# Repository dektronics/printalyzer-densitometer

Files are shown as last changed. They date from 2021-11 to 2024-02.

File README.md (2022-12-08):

# Printalyzer Densitometer

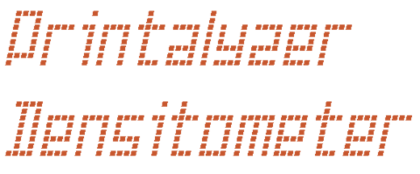
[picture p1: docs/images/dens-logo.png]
Printalyzer Densitometer Logo


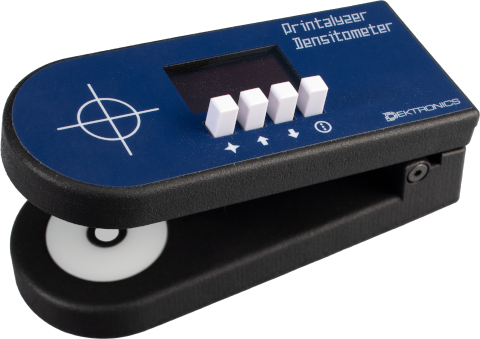
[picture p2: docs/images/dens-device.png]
Printalyzer Densitometer Device


## Introduction

The Printalyzer Densitometer is a project whose goal is the creation of an
affordable reflection and transmission densitometer for photographic darkroom
use.

It was initially conceived as an accessory to complement the
[Printalyzer Enlarging Timer & Exposure Meter](https://github.com/dektronics/printalyzer-timer)
to ease the process of creating paper profiles. However, given the general
utility of such a device, it has been spun off as a separate project in its
own right.

A good overview of the project can be found in these blog posts:
* [The Printalyzer Densitometer Project](https://hecgeek.blogspot.com/2021/07/the-printalyzer-densitometer-project.html)

This project, using hardware tagged as "Revision C" and labeled as DPD-100, is currently shipping as an official Dektronics [product](https://www.dektronics.com/printalyzer-densitometer). Links to the user manual and regulatory compliance documents can be found on the product website.

## Project Layout

### Hardware
The "hardware" directory contains [KiCad](https://www.kicad.org/) projects
with the complete circuit schematics, bill-of-materials, and
PCB layouts.

### Software
The "software" directory contains all the source code for the firmware
that runs on the hardware.

### Enclosure
The "enclosure" directory contains any CAD models and related resources
necessary to physically assemble the device.

## License
Individual directories will contain LICENSE files as needed, with relevant
details. Generally, the hardware will be CC BY-SA and the software will be
BSD 3-Clause. However, external resources may have their own individual license terms.

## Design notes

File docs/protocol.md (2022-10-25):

USB Control Protocol
====================

The Printalyzer Densitometer presents itself to a host computer as a USB CDC
device, which is essentially a virtual serial port. Through this interface,
it is possible to configure and control all aspects of the device.
This document covers that protocol.

## Data Formats

All command and response lines are terminated by a CRLF (`\r\n`).

### Command Format

Each command is sent in a standardized form:

`<TYPE><CATEGORY> <ACTION>[,<ARGS>]`
* **TYPE** values:
  * `S` - Set (change a value or state)
  * `G` - Get (return a value or state)
  * `I` - Invoke (perform some action on the system)
* **CATEGORY** values:
  * `S` - System (top-level system commands)
  * `M` - Measurement (commands related to density measurements)
  * `C` - Calibration (commands related to device calibration)
  * `D` - Diagnostics (general diagnostic commands)
* **ACTION** values are specific to each category, and documented in the following sections
* **ARGS** values are specific to each action, and not all actions may have them

### Response Format

Command responses typically fit a format that is a mirror of the command that
triggered them, except the `[,<ARGS>]` field is changed to represent
information specific to that particular command response.

The common formats for these response arguments are:
* `OK` - The command completed successfully, with no further information
* `ERR` - The command failed
* `NAK` - The command was either unrecognized or can't be processed in the current system state
* `A,B,C,D` - A comma-separated list of elements
  * Strings in this list may be quoted
  * Floating point values are returned in a little-endian hex encoded format
* A multi-line response as follows:
  ```
  TC ACTION,[[\r\n
  Line 1
  Line 2
  ...
  ]]\r\n  
  ```

### Density Format

Density readings are sent out-of-band whenever a reading is taken on the device,
and are not sent in response to commands. They follow the format of:

`<R/T><+/->#.##D`

An example of a density reading would be something like `R+0.20D` or `T+2.85D`.

### Logging Format

Redirected log messages have a unique prefix of `L/`, where "L" is the logging level.
By looking for this pattern, they can be filtered out from the rest of the command
protocol. By default, log messages are not redirected out the USB CDC interface.

Expected log levels include: `A`, `E`, `W`, `I`, `D`, and `V`

## Commands

Note: Commands that could conflict with the local device user interface
may require that the device first be placed into "remote control" mode.
If sent outside of this mode, they may fail with a **NAK**. Commands of
this type are marked below.

Commands that lack a documented response format will return either `OK` or `ERR`.

### System Commands

* `GS V` - Get project name and version
  * Response: `GS V,<Project name>,<Version>`
* `GS B` - Get firmware build information
  * Response: `GS B,<Build date>,<Build describe>,<Checksum>`
* `GS DEV`  - Get device information
  * Response: `GS DEV,<HAL Version>,<MCU Device ID>,<MCU Revision ID>,<SysClock Frequency>`
* `GS RTOS` - Get FreeRTOS information
  * Response: `GS RTOS,<FreeRTOS Version>,<Heap Free>,<Heap Watermark>,<Task Count>`
* `GS UID`  - Get device unique ID
  * Response: `GS UID,<UID>`
* `GS ISEN` - Internal sensor readings
  * Response: `GS ISEN,<VDDA>,<Temperature>`
  * Note: Response elements have unit suffixes appended, so it looks like "3300mV,24.5C"
* `IS REMOTE,n` - Invoke remote control mode (enable = 1, disable = 0)
  * Response: `IS REMOTE,n`
* `SS DISP,text` - Write the provided text to the display
  * Note: Line breaks are sent as the literal text "\n"
    and backslashes are sent as the literal text "\\"

### Measurement Commands

* `GM REFL` - Get last reflection measurement
  * Response: `GM REFL,<D>`
* `GM TRAN` - Get last transmission measurement
  * Response: `GM TRAN,<D>`
* `SM FORMAT,x` - Change measurement output format
  * Possible measurement formats are:
    * `BASIC` - The default format, which just includes the measurement mode
      and density value in a human-readable form, to 2 decimal places
    * `EXT` - Appends the density, zero offset, raw basic count,
      and slope corrected basic count sensor readings in the hex encoded format
  * Note: The active format will revert to **BASIC** upon disconnect
* `SM UNCAL,x` - Allow measurements without target calibration (0=false, 1=true)
  * Note: This setting will revert to false upon disconnect

### Calibration Commands

* `IC GAIN` - Invoke the sensor gain calibration process ***(remote mode)***
  * This is a long process in which the device must be held closed.
    It will automatically abort if the hinge detect switch is released
    during the process.
  * The result of this process will be updated measurement light and
    sensor gain calibration values.
  * While running, there will be a series of `STATUS` responses followed by
    a single `OK` or `ERR` response.
  * Status is reported via the following responses:
    * `IC GAIN,STATUS,n,m` where n is an enumerated value as follows:
      * 0 = initializing
      * 1 = measuring medium gain (m = 0 or 1)
      * 2 = measuring high gain (m = 0 or 1)
      * 3 = measuring maximum gain (m = 0 or 1)
      * 4 = calibration process failed
      * 5 = finding gain measurement brightness (m = progress)
      * 6 = waiting between measurements (m = index)
      * 7 = calibration process complete
    * `IC GAIN,OK` - Gain calibration process is complete
    * `IC GAIN,ERR` - Gain calibration process has failed
* `GC LIGHT` - Get measurement light calibration values
  * Response: `GC LIGHT,<REFL>,<TRAN>`
* `SC LIGHT,<REFL>,<TRAN>` - Set measurement light calibration values
  * The values set the duty cycle for the measurement lights, and are
    in the range of 1-128, with 128 indicating full brightness.
* `GC GAIN` - Get sensor gain calibration values
  * Response: `GC GAIN,<L0>,<L1>,<M0>,<M1>,<H0>,<H1>,<X0>,<X1>`
  * Note: `<L0>` and `<L1>` will always be equivalent to 1.0, as they represent
    the sensor's base gain value. They are only included for the sake of completeness.
* `SC GAIN,<M0>,<M1>,<H0>,<H1>,<X0>,<X1>` - Set sensor gain calibration values
  * Note: `<L0>` and `<L1>` are omitted from the set command as their value
    cannot be changed.
* `GC SLOPE` - Get sensor slope calibration values
  * Response: `GC SLOPE,<B0>,<B1>,<B2>`
* `SC SLOPE,<B0>,<B1>,<B2>` - Set sensor slope calibration values
  * _Note: There is no on-device way to perform slope calibration.
    It must be performed using the desktop application, and then
    loaded onto the device via the command interface._
* `GC REFL` - Get reflection density calibration values
  * Response: `GC REFL,<LD>,<LREADING>,<HD>,<HREADING>`
* `SC REFL,<LD>,<LREADING>,<HD>,<HREADING>` - Set reflection density calibration values
  * The reading values are assumed to be in slope corrected basic counts
* `GC TRAN` - Get transmission density calibration values
  * Response: `GC TRAN,<LD>,<LREADING>,<HD>,<HREADING>`
* `SC TRAN,<LD>,<LREADING>,<HD>,<HREADING>` - Get transmission density calibration values
  * The reading values are assumed to be in slope corrected basic counts
  * Note: `<HD>` is always zero, and only included here for the sake of consistency

### Diagnostic Commands

* `GD DISP` - Get display screenshot
  * Response is XBM data in the multi-line format described above
* `SD LR,nnn` -> Set reflection light duty cycle (nnn/127) ***(remote mode)***
  * Light sources are mutually exclusive. To turn both off, set either to 0.
    To turn on to full brightness, set to 128.
* `SD LT,nnn` -> Set transmission light duty cycle (nnn/127) ***(remote mode)***
  * Light sources are mutually exclusive. To turn both off, set either to 0.
    To turn on to full brightness, set to 128.
* `ID S,START` - Invoke sensor start ***(remote mode)***
  * When the sensor task is started via this diagnostic command, there is an
    implicit "Get Reading" command every time a result is available. Thus,
    results are periodically returned as long as the task is running.
  * Result format: `GD S,<CH0>,<CH1>,<GAIN>,<TIME>`
* `ID S,STOP` - Invoke sensor stop ***(remote mode)***
* `SD S,CFG,n,m` - Set sensor gain (n = [0-3]) and integration time (m = [0-5]) ***(remote mode)***
* `ID READ,<L>,<N>,<M>` - Perform controlled sensor target read ***(remote mode)***
  * `<L>` - Measurement light source
    * `0` - Light off
    * `R` - Reflection light, full power
    * `T` - Transmission light, full power
  * `<N>` - Sensor gain (0-3)
  * `<M>` - Sensor integration time (0-5)
  * Result format: `ID READ,<CH0>,<CH1>`
  * Note: This operation behaves similarly to a real measurement, synchronizing
    read light control to the measurement loop, and averaging across a number
    of readings. Unlike a real measurement it uses preconfigured gain and
    integration settings, rather than automatically adjusting them as part
    of the cycle, and returns raw sensor data. It is intended for use as part of
    device characterization routines where repeatable measurement conditions
    are necessary.
* `ID WIPE,<UID>,<CKSUM>` - Factory reset of configuration memory ***(remote mode)***
  * `<UIDw2>` is the last 4 bytes of the device UID, in hex format
  * `<CKSUM>` is the 4 byte checksum of the current firmware image, in hex format
  * _Note: After acknowledging this command, the device will perform the wipe
    and then reset itself. The connection will be lost in the process._
* `SD LOG,U` -> Set logging output to USB CDC device
* `SD LOG,D` -> Set logging output to debug port UART (default)

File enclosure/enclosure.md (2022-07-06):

# Printalyzer Densitometer Enclosure

## Introduction

This directory contains all the assets necessary to produce the physical
enclosures for the Printalyzer Densitometer. This document explains what
component each file represents, and also provides a bill-of-materials
for additional hardware needed for assembly.

The actual assembly instructions are located elsewhere.

## 3D Models

Models designed for 3D printing are provided as both STL and 3MF files,
and are listed without their file extension.

Original CAD files are provided in the native format of the CAD application.

The models that make up the construction of the device must be printed
in a material that is minimally reflective and opaque to both visible and
infrared light.

_**Note: Many of the models for components beyond the main enclosure were
created by deriving from either the main assembly CAD project or related
projects that might include non-distributable models of 3rd party
components. As such, original CAD files may not be provided for everything
listed here.**_

These files are in the `models_3d` subdirectory.

### CAD Projects

* `dens-enclosure.f3z` - Main CAD model for the enclosure, designed in Fusion 360.  
  (_Note: Does not include models of the PCBs or mounting hardware, to avoid
  accidentally redistributing component models that are under restrictive
  license terms._)

### Main Enclosure Components

* `dens-main-housing` - Main housing for the circuit board and major components
* `dens-main-cover` - Top cover for the main housing
* `dens-main-cover-dev` - Alternative top cover with a clearance hole for a debug connector
* `dens-base` - Base housing that contains the transmission LED components
* `dens-base-cover` - Bottom cover for the base housing

### Internal Components

* `diffuser-spacer` - Spacer that sits between the diffuser material and the UV/IR filter
* `filter-ring` - Ring that sits between the UV/IR filter and the main circuit board
* `sensor-board-cover` - Internal cover for the backside of the circuit board above the sensor elements

### Assembly Jigs

* `jig-dens-main-assembly` - Jig to hold the main housing during assembly
* `jig-dens-base-assembly` - Jig to hold the base, upside down, during assembly
* `jig-display-mounting` - Jig to help align the PCB and OLED display for assembly
* `jig-overlay-mounting` - Jig to help align the main cover and graphic overlay for assembly
* `jig-spring-trimmer-base` - Base portion of a jig to help hold the torsion springs
  in place while trimming them with a rotary tool
* `jig-spring-trimmer-cover` - Cover portion of a jig to help hold the torsion springs
  in place while trimming them with a rotary tool
* `jig-upside-down` - Jig to hold the complete device in an upside-down orientation,
  which is useful for mating the top and bottom halves and for installing the base cover
* `jig-cal-strip-measure` - Jig for holding a calibration reference for measurement,
  when the label markings have not yet been applied

## 2D Models

Models designed for laser cutting are provided as DXF files.
They are provided in both single-part and multi-part grid versions.

These files are in the `models_2d` subdirectory.

* `stage-plate-rings.dxf` - Components that make up the stage plate outer ring
  and transmission LED diffuser. Cut from a matte white acrylic material that
  is 3mm thick.
* `filter-ring.dxf` - Alternative version of the filter ring 3D model from
  above. Must be cut from a clean opaque material that is 3mm thick.
* `sensor-board-cover.dxf` - Alternative version of the sensor board cover
  from above. Must be cut from a material that is opaque to visible and
  infrared light and that is approximately 1mm thick. If thicker, then the
  mounting screws in the sensor head area will need to be longer.

## Graphic Overlay

The graphic overlay is a piece of custom cut polycarbonate material
that has printing and a transparent window for the display.
For all device builds so far, it has been ordered from [JRPanel](https://www.jrpanel.com/).
These files are the design artifacts that have been used when placing
that order.

These files are in the `overlay` subdirectory.

* `graphic-overlay-dims.pdf` - CAD drawing showing all the relevant
  dimensions of the overlay
* `graphic-overlay.dxf` - 2D CAD file representing the relevant
  dimensions of the overlay
* `graphic-overlay.svg` - Inkscape design for the overlay, annotated as appropriate.
* `graphic-overlay.pdf` - PDF export of the design, for ease of exchange.

## Product Labels

* TBD

## Additional Components

### Non-PCB Electronic Components

These are components that are not included in the PCB's bill-of-materials,
but are ordered from the same kinds of vendors and are necessary to assemble
a complete device.

* Button caps (x4)
  * **E-Switch 1SWHT**
  * Mouser PN: 612-1S-WHT
* 1.3" OLED Display Screen
  * **ER-OLED013A1-1W**
  * https://www.buydisplay.com/white-1-3-inch-oled-i2c-arduino-ssd1306-display-module-connector-fpc
* Cable to connect Transmission LED Board to Main Board
  * **JST JUMPER 02SR-3S -02SR-3S 4"**
  * Manufacturer PN: A02SR02SR30K102A
  * Digi-Key PN: 455-3619-ND

### Non-Electronic Components

These components are not necessarily sourced from electronics vendors, but
are still necessary for the assembly of the device.

* Diffuser material, cut to slightly smaller than 15x15mm
  * **LGT188-T** (0.21mm thick, matte & glossy, 90.60% opacity)
  * Sourced from AliExpress
  * https://www.aliexpress.com/item/4000604712643.html
* UV/IR Filter, 14mm diameter
  * Sourced from AliExpress
  * https://www.aliexpress.com/item/4001222435297.html

## Assembly Hardware

* M2 x 4mm thread forming screws (x2)
  * McMaster-Carr PN: 90380A324
* M2 x 5mm thread forming screws (x6)
  * McMaster-Carr PN: 90380A325
* M2 x 8mm thread forming screws (x4)
  * McMaster-Carr PN: 90380A327
* M2 x 8mm flat head black screws (x4)
  * McMaster-Carr PN: 91698A204
* M3 x 20mm low-profile socket head partially threaded screws (x2)
  * McMaster-Carr PN: 93070A076
* Torsion Spring, 180 deg Right-Hand wound
  * McMaster-Carr PN: 9271K97
* Torsion Spring, 180 deg Left-Hand wound
  * McMaster-Carr PN: 9271K98
* Flanged sleeve bearings for 3mm shaft, 5mm long (x2)
  * McMaster-Carr PN: 2705T112
* Rubber bumbers (x4)
  * **3M BUMPER CYLIN 0.315" DIA BLACK**
  * Manufacturer PN: SJ5076
  * Digi-Key PN: 3M156065-ND
* Adhesive wheel weights, 1/4 oz (x6)
  * Available from a variety of vendors
* Silicone adhesive
  * **Chipquik NCS10G**
* Foam mounting tape (3/4"x 15ft)
  * **3M VHB 3/4-5-4991**
  * McMaster-Carr PN: 8127A88

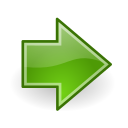
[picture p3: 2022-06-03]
software/desktop/assets/images/go-next.png

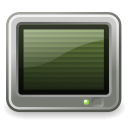
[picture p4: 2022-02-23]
software/desktop/assets/images/logger.png

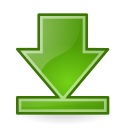
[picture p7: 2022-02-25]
software/desktop/assets/images/go-bottom.png

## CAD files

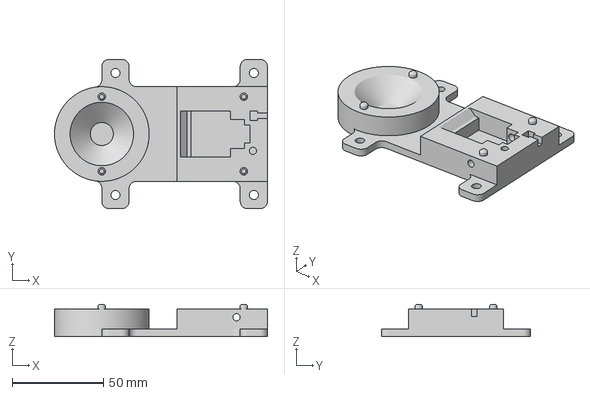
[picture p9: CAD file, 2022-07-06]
enclosure/models_3d/jig-dens-main-assembly.3mf
117.0 x 82.0 x 17.6 mm

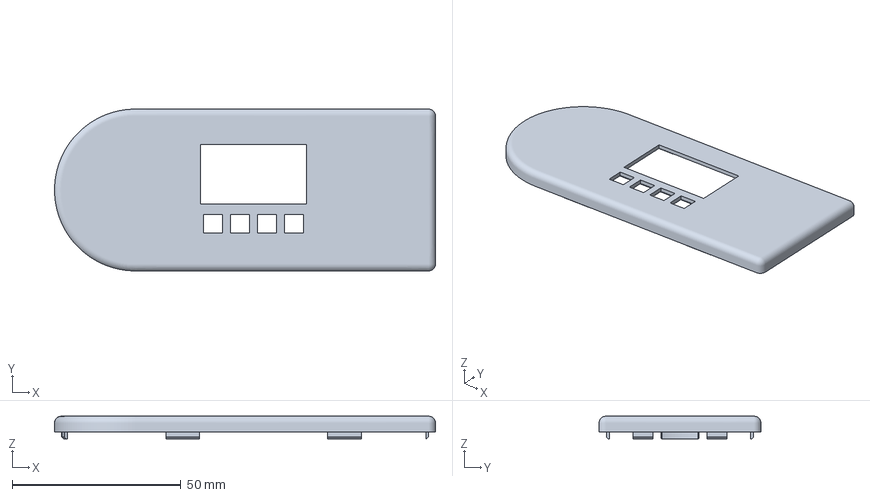
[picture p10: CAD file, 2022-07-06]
enclosure/models_3d/dens-main-cover.3mf
113.0 x 48.0 x 6.70 mm

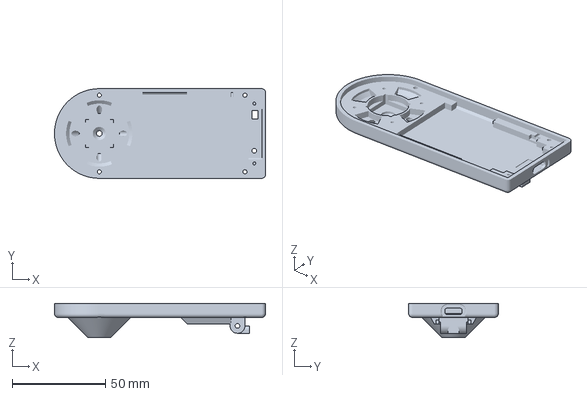
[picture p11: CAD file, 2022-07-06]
enclosure/models_3d/dens-main-housing.3mf
113.0 x 48.0 x 18.3 mm

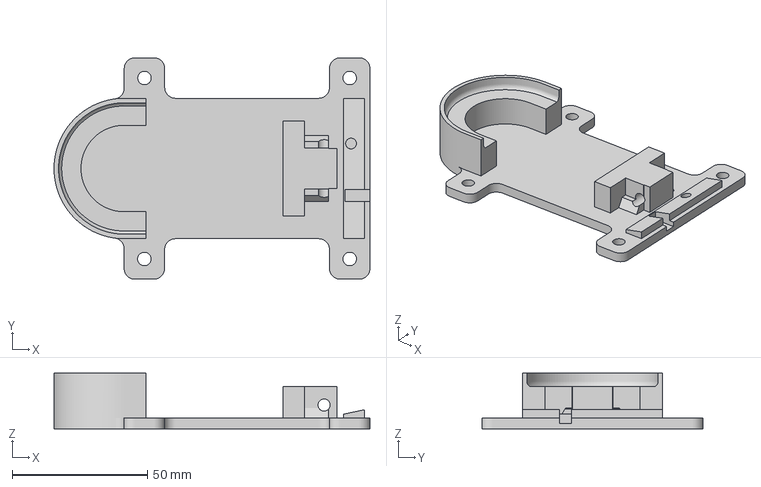
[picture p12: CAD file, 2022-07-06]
enclosure/models_3d/jig-dens-base-assembly.3mf
117.0 x 82.0 x 20.6 mm

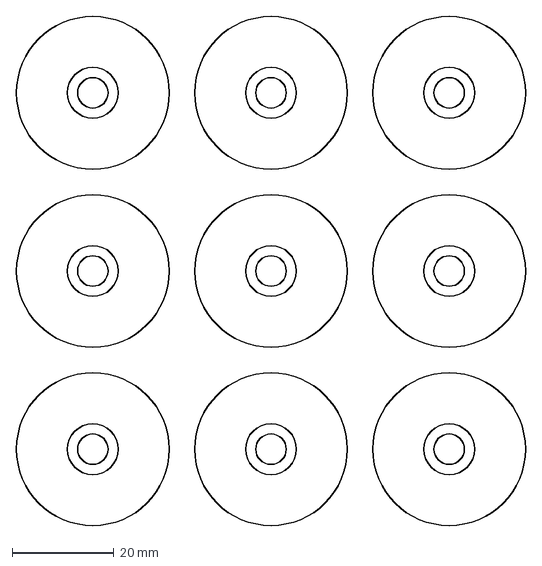
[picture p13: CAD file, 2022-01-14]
enclosure/models_2d/stage-plate-rings-3x3.dxf
100.0 x 100.0 mm

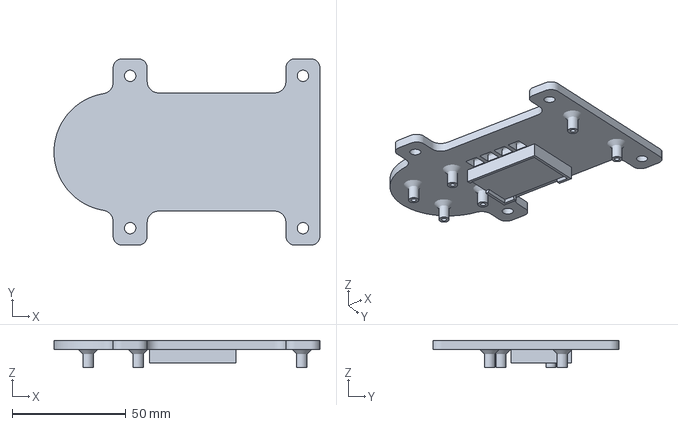
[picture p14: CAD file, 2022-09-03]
enclosure/models_3d/jig-display-mounting.3mf
117.0 x 82.0 x 12.0 mm

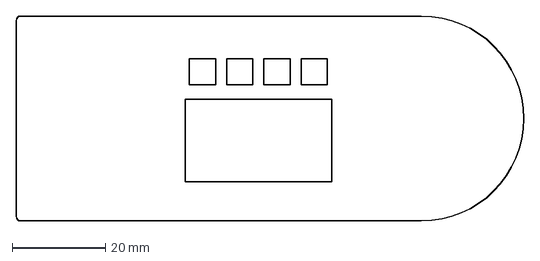
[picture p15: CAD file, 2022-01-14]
enclosure/overlay/graphic-overlay.dxf
109.0 x 44.0 mm

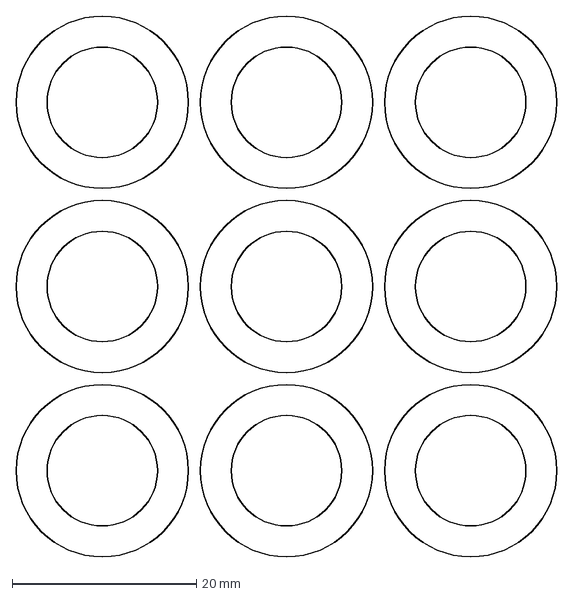
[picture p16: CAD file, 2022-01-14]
enclosure/models_2d/filter-ring-3x3.dxf
58.7 x 58.7 mm

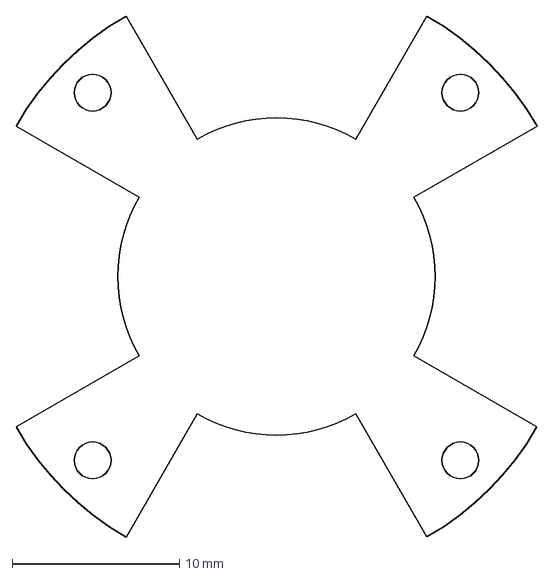
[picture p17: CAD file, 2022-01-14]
enclosure/models_2d/sensor-board-cover.dxf
31.2 x 31.2 mm

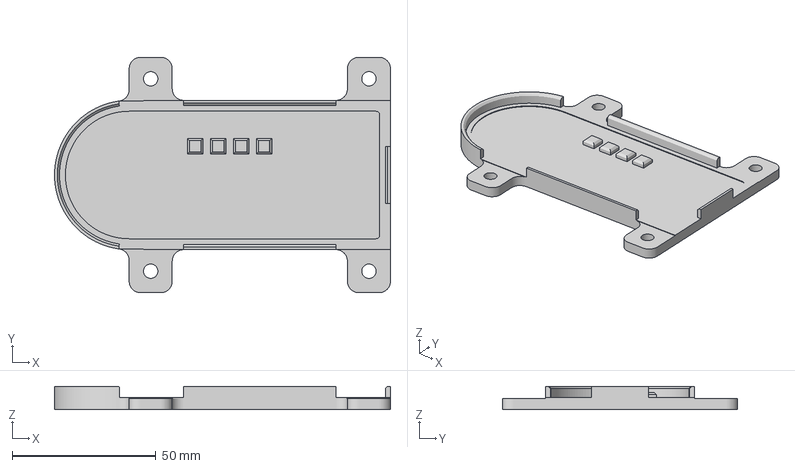
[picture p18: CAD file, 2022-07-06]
enclosure/models_3d/jig-overlay-mounting.3mf
117.0 x 82.0 x 8.18 mm

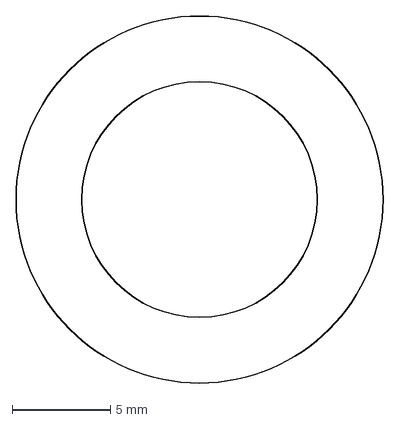
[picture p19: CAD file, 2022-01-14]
enclosure/models_2d/filter-ring.dxf
18.7 x 18.7 mm

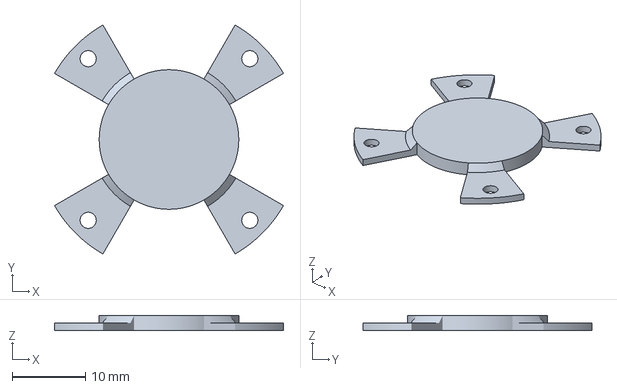
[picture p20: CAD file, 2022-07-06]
enclosure/models_3d/sensor-board-cover.3mf
31.2 x 31.2 x 2.00 mm

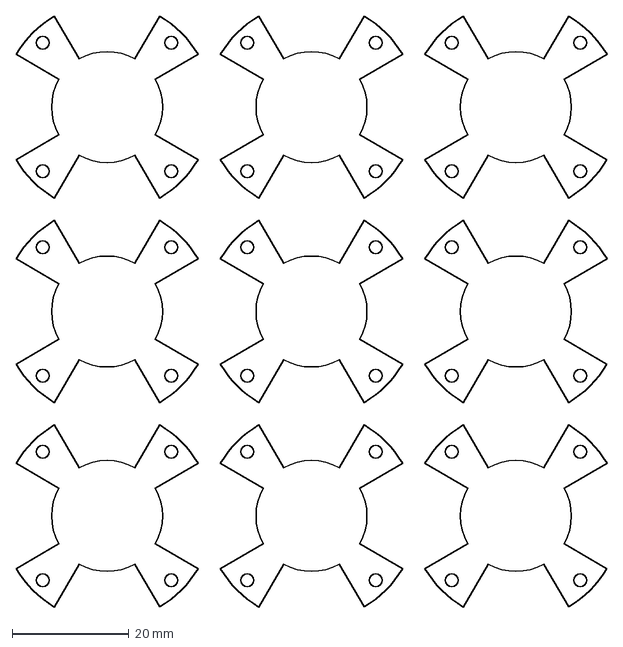
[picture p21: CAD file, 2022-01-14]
enclosure/models_2d/sensor-board-cover-3x3.dxf
101.2 x 101.2 mm

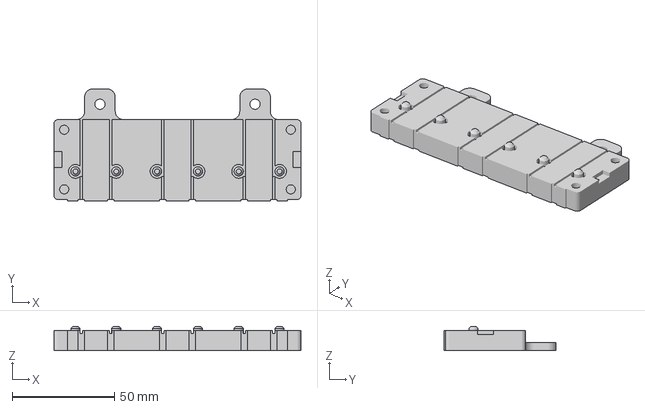
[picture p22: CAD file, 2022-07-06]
enclosure/models_3d/jig-spring-trimmer-base.3mf
121.0 x 55.0 x 12.0 mm

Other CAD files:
enclosure/models_3d/dens-main-cover-dev.3mf
enclosure/models_2d/stage-plate-rings.dxf
enclosure/models_3d/jig-upside-down.3mf
enclosure/models_3d/dens-base-cover.3mf
enclosure/models_3d/dens-base-cover.stl
enclosure/models_3d/dens-base.3mf
enclosure/models_3d/dens-base.stl
enclosure/models_3d/dens-enclosure.f3z
enclosure/models_3d/dens-main-cover-dev.stl
enclosure/models_3d/dens-main-cover.stl
enclosure/models_3d/dens-main-housing.stl
enclosure/models_3d/diffuser-spacer.3mf
enclosure/models_3d/diffuser-spacer.stl
enclosure/models_3d/filter-ring.3mf
enclosure/models_3d/filter-ring.stl
enclosure/models_3d/jig-cal-strip-measure.3mf
enclosure/models_3d/jig-cal-strip-measure.stl
enclosure/models_3d/jig-dens-base-assembly.stl
enclosure/models_3d/jig-dens-main-assembly.stl
enclosure/models_3d/jig-display-mounting.stl
enclosure/models_3d/jig-overlay-mounting.stl
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

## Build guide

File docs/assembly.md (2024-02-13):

Printalyzer Densitometer Assembly
=================================

This document describes the process of assembling a complete
Printalyzer Densitometer from its major components. It assumes that the
assembly of printed circuit boards, along with any soldered-in components,
has been performed prior to following this document. The steps laid out
herein are written with the assumption that they are performed in sequential
order. In practice, independent steps may be reordered as appropriate for
batch assembly.

The majority of the bill-of-materials for this process is contained within
the [enclosure](../enclosure/enclosure.md) document. Please refer there for
detailed descriptions and part numbers for any components listed here.

## Main Board Assembly

### Components

* Main Board (assembled PCB)
* Button caps (x4)
* OLED Display Screen
* Foam mounting tape

### Tools

* Display mounting jig (`jig-display-mounting`)
* Knife or scissors

### Steps

* Mount the display
  * Cut a 3cm piece of mounting tape, and affix to the main board over the
    recangular silkscreen markings that represent the center of a display
    component.
  * Insert the display screen, face-down, into the recessed rectangular area
    on the display mounting jig. Do not remove the protective cover.
  * Remove the outer film from the mounting tape, exposing the rest of the
    adhesive.
  * Carefully lower the main board onto the dowel pins sticking up from the
    mounting jig, until the display is affixed to the tape.
  * Remove the main board from the jig, and carefully apply additional
    pressure with your fingers to ensure everything is securely in place.
  * Insert the display flat flex cable into the socket on the opposing side
    of the main board, and lock it in place with the socket tabs.
* Press-fit the button caps onto the tactile switches on the main board.

## Base

### Components

* Base housing (`dens-base`)
* Stage Plate Outer Ring (`stage-plate-rings`)
* Stage Plate Diffuser (`stage-plate-rings`)
* Transmission Board (assembled PCB)
* Adhesive wheel weights (x6)
* Jumper cable assembly
* M2 x 4mm thread forming screws (x2)

### Tools
 * Base assembly jig (`jig-dens-base-assembly`)
 * Scrap paper
 * Toothpick
 * Wedge-shaped piece of plastic (cut zip-tie end will work)
 * Screwdriver
 * Knife
 * Silicone adhesive
 * Cyanoacrylate glue (liquid and gel)

### Steps

* Affix stage plate components
  * Squirt a blob of cyanoacrylate glue gel onto a scrap of paper
  * Use a toothpick to apply the glue gel to the inside of the diffuser
    hole in the base housing, near the ridge at the bottom of the hole.
    Be very careful, and use a minimal amount.
  * Insert the stage plate diffuser into the hole, matte side up, and
    press down firmly.
  * Squirt a bead of cyanoacrylate glue liquid around the stage plate outer
    ring recess in the base housing. Use a minimal amound, preferably in a
    circle around the midpoint.
  * Insert the stage plate outer ring, matte side up, and press down firmly.
  * Let the piece sit and allow the glue to dry.
* Place the base housing upside-down in the base assembly jig.
* Affix adhesive weights
  * Use a knife on a hard surface to cut the wheel weights into four distinct
    pieces; two singles and two pairs.
  * Remove the backing paper and press the pieces into the underside of the base.
    The singles go near the front of the recess, and the pairs go behind them.
    (see picture)
  * Squirt beads of silicone adhesive into all the crevaces surrounding the
    weights, and use the wedge-shaped plastic as a spatula to smooth it out.
  * Allow to dry for 24 hours.
* Install transmission board
  * Place the board into its spot, and secure with screws.
  * Attach the cable assembly to the board connector.
  * Loop the cable if necessary, for length.
  * Feed the cable out through the cable hole at the rear of the base.

## Base Cover

### Components

* Base cover (`dens-base-cover`)
* Product label
* Rubber bumbers (x4)
* M2 x 8mm flat head black screws (x4)

### Tools

* Base assembly jig (`jig-dens-base-assembly`)
* Screwdriver

### Steps

* Place the Base housing sub-assembly upside-down in the base assembly jig.
* Place cover over the Base housing sub-assembly, and secure with screws
* Apply rubber bumpers in the indents over the screws
* Affix the product label to its indent (can leave this step to the very end)

## Main Housing

### Components

* Main Housing (`dens-main`)
* Diffuser spacer (`diffuser-spacer`)
* Filter ring (`filter-ring`)
* Sensor Board Cover (`sensor-board-cover`)
* Diffuser material sheet
* UV-IR cut filter
* Main Board Assembly
* M2 x 5mm thread forming screws (x6)

### Tools

* Main housing assembly jig (`jig-dens-main-assembly`)
* Screwdriver
* Scissors or rotary trimmer
* Microfiber cloth

### Steps

* Cut a piece of the diffuser material that is just over 14x14mm.
  (It needs to fit into a 15x15mm recess, so some clearance is desired.)
* Place the Main Housing into the Main housing assembly jig.
* Insert the cut diffuser material into body's sensor cone recess,
  matte side up.
* Insert the UV-IR cut filter into the diffuser spacer, and then
  place the combined sub-assembly on top of the diffuser.
  (These parts are best handled with the aid of a microfiber cloth,
  to avoid smudges.)
* Insert the filter ring on top.
* Place the Main Board Assembly into the housing
* Place the Sensor Board Cover on top of the Main Board Assembly.
* Secure with screws the board with screws

## Main Cover

### Components

* Main Cover (`main-cover`)
* Graphic Overlay
* Main Housing Assembly
* M2 x 8mm thread forming screws (x4)

### Tools

* Overlay mounting jig (`jig-overlay-mounting`)
* Screwdriver

### Steps

* If the protective cover over the display window on the graphic overlay is
  encroaching on the button holes, then move it as necessary.
* Place the graphic overlay face-down into the jig
* Carefully remove the backing material from the graphic overlay.
* Align and place the main cover, face down, onto the overlay.
* Remove the main cover, and press on a hard surface to make
  sure the overlay is well adhered.
* Remove the protective cover from the mounted display, which is on
  the main board which is installed within the main housing assembly.
* Place the main cover onto the main housing assembly,
  and secure with screws

_Note: The display window cover on the outer surface of the graphic overlay
should probably be left on through shipping, and removed by the end user._

## Final Assembly

### Components

* Main Body Assembly (Main Body + Main Body Cover)
* Base Assembly (Base + Base Cover)
* RH Torsion Spring
* LH Torsion Spring
* Flange sleeve bearings (x2)
* M3 x 20mm low-profile socket head partially threaded screws (x2)

### Tools

* Spring trimmer jig (`jig-spring-trimmer-base` and `jig-spring-trimmer-cover`)
* Rotary tool with cut-off disc
* Screwdriver

### Steps

* Insert springs into the trimmer jig, and cut ~12mm off the bottom end of
  each one using a rotary tool.
* Take trimmed springs, and insert them into the base assembly hinge area
* Insert the flange sleeve bearings onto the inside-facing spring hole,
  and insert the hinge screws from the outside to hold them in place.
* Connect the transmission LED cable to the Main Body Assembly.
* Carefully install the main body assembly onto the spring tines
  and hinge screw/flange assembly.
* Tighten the hinge screws, alternating, to keep centered alignment.

## Post-Assembly

These steps are just a rough outline of the final part of the process, and
will be further refined once the device is in production.

* Install the bootloader, either pre-loading prior to assembly or via
  USB DFU after assembly.
* Install the firmware, either pre-loading prior to assembly or via
  USB DFU/UF2 after assembly.
* Load the "factory" sensor slope calibration data.
* Run the sensor gain calibration routine.
* Calibrate reflection and transmission modes againt references
  to be included with the package.

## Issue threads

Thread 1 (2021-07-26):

Connect interrupt pin on light sensor

dkonigsberg, 2021-07-26:
The TSL2591 light sensor has an interrupt pin that is currently unconnected.  The reason it is unconnected is that when the hardware was being designed, it didn't appear as though the sensor's interrupt feature would be useful for our use cases.

As a result of learning more about how to effectively use the sensor, it now seems as though the interrupt feature is useful. It can be used as a way of synchronizing code to the ADC integration cycles of the sensor. (Without the interrupt pin, this can only be done via I2C polling of a status register.)

So in the next hardware revision, the INT pin should be connected to the MCU.

dkonigsberg, 2021-10-10:
Implemented on main board rev B.

Closed 2021-10-10.

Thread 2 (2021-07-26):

Investigate alternatives for tactile switches

dkonigsberg, 2021-07-26:
The current prototypes use the E-Switch TL1105SPF160Q tactile switches for the user input buttons.
The problem with these switches is that the only off-the-shelf button caps are way too tall (9mm) for the device enclosure design. Their plungers are also 2.8x2.8mm square, which may be limited for custom cap options.

Another switch worth investigating is the Omron B3F-1052.  It has the same PCB footprint, but with a smaller 2.4x2.4mm plunger and more off-the-shelf button cap choices. The main choices include square and round caps that are only 5.5mm tall.

The only problem which all of these choices present, is that the off-the-shelf caps may require more of a PCB-to-exterior gap than is desirable to hide the slits on their sides. (There's a limit to how far off the board the display can be mounted, which is a factor here.)  So whatever is used, custom button caps may still be necessary.

dkonigsberg, 2021-08-03:
The off-the-shelf caps for the Omron B3F series unfortunately have cutouts on the side. These cutouts prevent the top of the enclosure from being as thin as desired. (It needs to be thin to make up for the fact that the OLED display can't easily be mounted very high above the PCB.)

The only off-the-shelf caps that don't have these cutouts are the square ones from E-Switch, even if they are a bit too tall.

As such, changing tactile switches may not make sense after all. However, custom 3D printed switch caps for the existing switches are still being investigated.

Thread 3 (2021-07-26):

Standardize on a set of calibration references

dkonigsberg, 2021-07-26:
The product documentation should standardize on the calibration references that are used, and which patches from them are to be considered "CAL-HI" and "CAL-LO" for the various use cases. This may also involve designing custom labels that can be applied to these items.

Right now, the best choices seem to be the following products from [Stouffer Graphic Arts](https://www.stouffer.net/):

- R550 (Reflection step tablet, 5-step)
- T5100 (Transmission step wedge, 5-step)

Both of these come in "calibrated" and "uncalibrated" versions. Anyone building the device for themselves should probably spend the extra money for the calibrated version.  When building the device in quantity for sale, it makes more sense to buy the uncalibrated versions and calibrate them as part of the manufacturing process.

dkonigsberg, 2021-11-14:
While there may still be some room for discussion on exactly how to setup the manufacturing calibration process, the path forward for "official" included-with-the-product calibration strips has been decided. It is going to be the Stouffer R550 and T5100.  (For bulk production, they will be calibrated against an official reference as part of the assembly process. For one-off builds, buying the already-calibrated version will be recommended.

As such, the only remaining to-do item on this issue is to develop a set of standard labels to apply to these references, on which measured calibration values can be written.

dkonigsberg, 2022-05-03:
Labels are done, though their format is proprietary to the [ZebraDesigner](https://www.zebra.com/us/en/products/software/barcode-printers/print-dna/zebra-designer.html) label printer software. Furthermore, it is as of yet unclear how standalone or distributable those files are. For now, they'll be kept out of the repository, but that could change in the future.

Closed 2022-05-03.

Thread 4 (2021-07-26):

Provide a way for end-users to update device firmware

dkonigsberg, 2021-07-26:
While it is the hope that a "launch" version of the device will effectively have finalized firmware, the possibility for future updates to fix bugs and add features will always remain.

Its probably not reasonable to expect average end-users to use an ST-Link with a Tag-Connect cable to install firmware updates on the device. Therefore, another option should be provided.

The biggest issue right now is that the current firmware build (which is not feature-complete, but is close) already uses up most of the available flash on the STM32L052 microcontroller. Furthermore, the built-in bootloader options on this MCU are really not suitable for handling end-user firmware updates.

The solutions to this problem can be broken up into two categories:
- Optimize the build enough that we can make 8-16kb of space, and use a 3rd party bootloader to facilitate updates
- Switch to a 128kb+ MCU that has a built-in USB DFU bootloader and provide a means of using that
  - Right now, due to the great microcontroller shortage, options for this are limited and expensive (especially within the L0 line).

Options for a tiny cram-able bootloader include these projects:
- [LED Wristwatch Bootloader](https://github.com/kcuzner/led-watch/tree/master/bootloader)
  - Actually designed for the STM32L052
  - Fits in 8kb
  - Works by simulating a USB HID device, so some sort of custom software will be required on the host side to facilitate installing firmware updates
  - MIT License
- [DFU Bootloader](https://github.com/IntergatedCircuits/DfuBootloader)
  - Also claims to fit within 8kb
  - Works via USB DFU, which is preferred
  - Does not support the L0, so it will require porting.  (Does support the F0, F3, F4, and L4. No idea how similar they are.)
  - Apache License 2.0

dkonigsberg, 2021-10-10:
As of recent updates, there is now a very basic way of doing this:
1. Hold down boot selector button with device powered off
2. Plug in device to a computer
3. Device shows up as a USB DFU device (with both LED sets on, for some reason)
4. `$ dfu-util -a 0 --dfuse-address 0x08000000 -D densitometer.bin`
5. Power-cycle the device

A more polished version is going to need a few additions, that may or may not end up as separate issues:
- Add instructions and/or build steps to run `dfuse-pack.py` to make a proper DFU file
- Implement version descriptor data into the firmware build
- Add a way to query this version descriptor, both via the firmware itself and via a scripted sequence involving `dfu-util` and some processing of its output.
- Add a firmware feature to make the device restart itself into DFU mode without needing a hidden BOOT0 button and power cycle (but keep those for cases where the firmware has malfunctioned).
- Wrap this all up into an updater utility, either as a script or as part of a future desktop application.

dkonigsberg, 2021-11-11:
There are now two ways to update on-device firmware, so I think its time to close this issue:

1. The DFU method, as mentioned above. This is great for programming from a bare-metal state, and/or fixing a bricked device. It might be a little too involved for ordinary updates.
2. An embedded UF2 bootloader, triggered by holding down a button combination on power-up. This is very easy for an ordinary end-user to use to install updates. It may still have room for improvement, but in its current state it gets the job done.

pixelwaster, 2021-11-11:
You might want to check out the nanoVNA, The update process is very easy and they use a similar processor. Basically select the file, select the device, and update.

Very interesting project. Looking forward to seeing how this goes almost more than the densitometer itself.

dkonigsberg, 2021-11-11:
> You might want to check out the nanoVNA, The update process is very easy and they use a similar processor. Basically select the file, select the device, and update.
NanoVNA uses DFU. There are a few utilities that can be used to do a DFU update, some easier to get going than others, but none really intended for normal end users.  A polished DFU update process would require writing my own wrapper, and then dealing with OS-specific device issues.

The advantage of UF2 is that it requires no special software.  Just boot into UF2 mode, the device shows up as a USB mass storage device, drag-and-drop the file to it, and you're done.

Closed 2021-11-11.

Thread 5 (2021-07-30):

Provide a way to "zero" the meter on a measurement target

dkonigsberg, 2021-07-30:
It is a common use case to want to measure density relative to some "base" (unexposed film/paper area), rather than relative to the ISO-standard "zero" point. Having this ability would make it a lot easier to collect and compare measurements in the most common use cases.

As such, the this capability should be implemented as follows:

- Have a way to set the current reflection/transmission reading as the "zero" offset for that mode, from either the display or measurement states
- Make sure the "zero" offset is simply a linear offset applied to the result, and not used as part of the actual logarithmic density calculations
- Indicate (in the display state) whether a "zero" offset has been set
- Have a way to clear a currently-set "zero" offset, most likely from the display state.
- Make sure the "zero" offset is specific to the current measurement mode, and is not persisted across device restart. It is not considered part of device calibration.
- Implement display of negative density readings, to handle cases where a measurement is below the "zero" offset point.

dkonigsberg, 2021-08-22:
Initial implementation provided by commit:
f6bdefde03eea467675780d40794cb0f69a6a169

Probably needs more polish, which might depend on fancier key input handling first.

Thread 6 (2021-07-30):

Make the local UI and the USB control protocol coexist better

dkonigsberg, 2021-07-30:
Right now the device can be controlled via either its local UI, or via a documented USB control protocol. The problem is that as the local UI becomes more polished and stateful, behavior conflicts may arise. This is especially true for the diagnostic commands, but can easily affect all other commands as well.

The whole USB control protocol needs to be reviewed, and it should be determined how certain commands shall behave in relation to the current UI state. For some commands (especially the diagnostic ones), it may even make sense to require the device be put into some sort of "remote control" state that locks the local UI while the USB control protocol is being used.

Of course none of this should affect output of measurements via USB, which should be considered an independent feature from device control.

dkonigsberg, 2021-10-10:
Switching over to a FreeRTOS task-based runtime architecture has made this issue more pressing.
Since the local UI and the CDC interface (USB control protocol) now run simultaneously, conflicts are even more likely.

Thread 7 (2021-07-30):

Standardize the USB control protocol command response format

dkonigsberg, 2021-07-30:
Right now a lot of the USB control protocol is designed with the assumption that the device is also being monitored via the debug serial port at the same time. Furthermore, command responses are somewhat loosely defined and not well standardized.

Every command needs a documented and standardized response format, and those responses need to be designed with the assumption that the user will not have access to the debug serial port.

Closed 2021-10-17.

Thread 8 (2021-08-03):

Switch to STM32L072Kxx series MCU

dkonigsberg, 2021-08-03:
The current (Rev A) design uses an STM32L052K8U MCU, which has 64k of flash, 8k of RAM, and no built-in bootloaders that are of use for #4. The firmware is also running out of headroom, bumping right up against the limit in size. There are still tricks that can be used to crunch it down a bit more, but things are getting uncomfortably close.

Switching to a STM32L072KBx (128k Flash, 20k RAM) or STM32L072KZx (192k Flash, 20k RAM) would have a number of advantages to the project:

- Inclusion of a [USB DFU](https://en.wikipedia.org/wiki/USB#Device_Firmware_Upgrade_mechanism) bootloader, which would allow end-users to more easily install firmware updates to the device
- Less constraints on firmware size, since most of the overhead is framework code that doesn't grow much with additional functionality
- The ability to use FreeRTOS. This would make it possible to separate device functionality into separate tasks (sensor polling, keypad management, USB interface) and make overall operation smoother and cleaner.

The downside is that some design changes would be necessary. The pinout is slightly different, and the GPIO pins (for buttons) would move a bit. Also, there might need to be an additional hidden button to pull BOOT0 high to enable the DFU bootloader.

dkonigsberg, 2021-10-10:
Implemented on main board rev B.

Closed 2021-10-10.

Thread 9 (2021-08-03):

Investigate alternative constant-current LED driver ICs

dkonigsberg, 2021-08-03:
The current design uses two [AP2502KTR-G1](https://www.diodes.com/part/view/AP2502) ICs to drive the LEDs. While this chip does work fine, it currently is in short supply from all the usual distributors. As such, it may be necessary to switch to a different driver with similar capabilities.

One option appears to be the [MIC2841A](https://www.microchip.com/en-us/product/MIC2841A) which has similar specs. The package is smaller/different, however, so it is not a drop-in replacement.

Another option is to stick with the AP2502, scrounging off prototypes, until stock returns.

dkonigsberg, 2021-11-14:
There are enough AP2502 parts in the bin to get through the rest of prototyping, and a longer-lead order has been placed for manufacturing quantities.  As such, closing this issue.

Closed 2021-11-14.

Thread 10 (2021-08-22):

Use larger single-line TVS diodes

dkonigsberg, 2021-08-22:
The current design uses the ST [ESDALC6V1-1U2](https://www.st.com/en/protection-devices/esdalc6v1-1u2.html) TVS diode for all cases where we want to protect a single line. The problem is that this is an 0201 sized component, which is extremely small and difficult to handle. It also doesn't solder quite as flat on the board as other components for this reason.

A potential alternative is the ST [ESDALC6V1-1M2](https://www.st.com/en/protection-devices/esdalc6v1-1m2.html) TVS diode, which appears to have similar specifications. However, it is in a slightly larger (0402'ish sized) package, so its probably a better choice.

dkonigsberg, 2021-10-10:
Implemented on main board rev B.

Closed 2021-10-10.

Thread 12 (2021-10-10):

Implement slope correction for sensor readings

dkonigsberg, 2021-10-10:
Note: This can be considered part of the calibration process. In fact, if done well, it could be used entirely in lieu of the densitometer's traditional low/high point calibration routines. However, in practice, it is too involved to be done via the local on-device UI and is best left as part of the "factory calibration" process.

### The Problem
As light levels decrease, the TSL2591 light sensor tends to undercount detected light. With reflection measurements, enough light is still received with the CAL-HI target that this hasn't been much of a problem. With transmission measurements, however, the CAL-HI target is dim enough that this issue begins to show itself.

When doing normal calibration, with the CAL-HI point being undercounted, the errors in the resulting measurements tend to follow a bit of a curve. Readings in the middle of the scale are further off than either end. Picking a lower-density CAL-HI target won't help, because then readings at the dense end of the scale will be off even more.

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

What makes this whole situation more difficult, is that density is measured on a logarithmic scale. Therefore, even apparently small errors in raw sensor data on the dense end tend to get magnified to the point of causing noticeable errors in the resulting density readings.

### The Analysis
An analysis of sensor readings was conducted, using a calibrated step wedge, to compare actual vs expected readings from full-brightness all the way down to 3.83D (~0.01%) It was determined that, while these two values look close on a linear scale, if you take the logarithm of each one and compare that, a divergence is clear:
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

While this divergence might appear linear at first glance, it is not.  A graph specifically showing just this divergence appears to actually have its own curve:
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
This curve kinda looks like it could be estimated with a second-order polynomial.

### The Solution
From a calibrated step wedge, build a table of actual to expected light readings.  These readings will be in the unit known as "basic counts" (sensor data made independent of gain/integration settings). This table will range from max brightness (sensor reading with nothing in its path) all the way through each patch of the step wedge up to the max.

For each patch, the expected light reading can be calculated by "Lexp = Lmax / (10^D)" where D is the density of the step wedge at that patch.

Then construct a set of two arrays.  The X array consists of the log10 of each actual light reading, while the Y array consists of the log10 of each expected light reading.  (the first entry in each array, Lmax, should have the same value)

Perform a second order polynomial regression on these arrays, which will yield 3 constants.  These constants shall be known as P0, P1, and P2, and are the result of the slope calibration.

To implement a correction based on the slope calibration on-device, use some form of the following code:
```
float correct_slope(float p0, float p1, float p2, float measurement)
{
    float l_meas = log10f(measurement);
    float l_expect = p0 + (p1 * l_meas) + (p2 * powf(l_meas, 2));
    float corr_meas = powf(10, l_expect);
    return corr_meas
}
```
The corrected measurement, still in "basic count" units, can then be used for all subsequent processing with no changes elsewhere.

### Conclusion
The proposed solution is too involved to be practical to implement on-device. The most feasible approach is likely going to be doing it off-line (perhaps inside desktop software) and then loading the resulting calibration numbers into the device. It is as of yet unclear whether this process will need to be done for every single unit, or if it can be done on a coarser "batch" basis with individual units only needing the simpler 2-point calibration on top of it.

However, this hassle is well worth it. In preliminary testing, it gets the density error down to +/- 0.01D across the full range.
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
(Obviously results this good are not expected to hold across the full range of test materials and conditions, but starting here in an idealized test scenario dramatically improves our changes of sticking close enough beyond it.)

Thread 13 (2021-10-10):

Clean up loose ends inside the sensor task

dkonigsberg, 2021-10-10:
There are a fair number of TODO items still scattered around `task_sensor.c` that were left to the side when doing the initial FreeRTOS task migration project.  These mostly center around propagating device errors upward and preventing redundant commands from being sent.

Creating this task so these items are not forgotten, and get taken care of.

Closed 2021-10-11.

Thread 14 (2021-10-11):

Compensate for measured LED brightness dropoff

dkonigsberg, 2021-10-11:
When switching an LED set on in the system, the measured brightness changes over time.  Specifically, it tends to follow a curve that looks something like this:
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

At first glance, this appears to follow a curve that can be measured and predicted by doing logarithmic regression of light readings. In fact, over a long period of on-time, this method does work quite well.  The problem is that at the very start of the curve, when we're actually taking our relevant sensor readings, this method does not work so well. The initial drop is a bit steeper, such that this simple correction either makes little difference or even makes the resulting reading worse.

Regardless, code was written to perform this characterization measurement, before it was deemed inadequate:
31a15d8b59bc10416d43860e60e62a3b6012849c
820714de5791087c4b86e09f03da27471f3bf6b0

One thing that code did reveal, is that while the graphs look similar, this brightness drop is far worse with the transmission LED than with the reflection LEDs.  A likely cause is that the transmission LED is being driven with twice the current (40mA x 1 vs 20mA x 4), and is thus heating up more.

As such, this issue needs to be tackled from multiple angles.

First, the sensor gain calibration routine was rewritten to have an awareness of the issue:
31a15d8b59bc10416d43860e60e62a3b6012849c

Second, a revision of the transmission LED board was designed that dramatically increases heat sinking from the LED's center thermal pad:
9851340418bfb13fbbd49bb30c915e6bca7cbed2

The next likely steps on this task are as follows:

- Test the updated transmission LED board, and if it makes a measurable difference in either the drop effect or cooldown-recovery time, then apply the same footprint change to the reflection LEDs
- Rewrite the sensor target reading loop such that we're always averaging across readings taken after the exact same amount of LED "on time," regardless of any auto-gain behaviors the code might do.  This should hopefully mitigate the effects of this issue, so that multiple readings are more accurately comparable.

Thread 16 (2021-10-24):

Test and fix issues related to a new unit with empty configuration data

dkonigsberg, 2021-10-24:
Many functions of the unit are designed with the assumption that certain configuration values will be available, either for settings or calibration. Even if code is written to gracefully handle invalid values for those, the user experience isn't always pleasant. Since most development is not done with a blank unit, testing of these cases is easy to forget.

As such, the following items are needed:

- Add a USB-CDC command to clear the EEPROM back to a "factory" state, and design this command so it is difficult to send by accident
- Test the full user experience from a "factory" state, and make sure the device behaves acceptably. This can include adding user notices warning of incomplete/invalid calibration, and maybe even a disabling of certain functions.
- Test cases where configuration values are added after the initial "bring up", as would happen via firmware updates. This doesn't need to be handled gracefully on pre-production prototype firmware, but does need to be graceful once the first unit "ships."

dkonigsberg, 2022-02-21:
This has been implemented across a whole slew of recent commits, starting with a redesign of the settings storage format (c8cd9291fb9053c4a3e5e4c53b0443e526dcf847, 862454b190d042c681998599af235c9c2361fcd9, 1b9c79f1850ab4b6f2d6130562418cb41486427a), followed by better handling of a device missing calibration data (a29d904eb9a51ebd9176bd79b7122c21f0fddd74, 90d9e1b396c721486d82a8b02b77eccd0352bd3d, c6d83e6269aaad73fc66c84e648b3c9a4f2a8bb4), and ending with the addition of an EEPROM clearing command (31e924f358303a8003fc0f4537be32b1e2f83e56).

Closed 2022-02-21.

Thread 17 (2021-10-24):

Integrate a desktop application into the project

dkonigsberg, 2021-10-24:
As a necessary companion to the device and its USB-CDC control interface, a desktop application needs to be included. This application, at a minimum, should include:

- Implementations of the majority of supported USB-CDC interface commands
- Ability to receive and display measurements from the device
- Diagnostic functions to display device information and support development
- Calibration functions to get/set all the usual calibration values
- Extended calibration functions, to support calibrations too difficult or cumbersome to implement entirely on-device (e.g. slope calibration)
- Tools to ease the firmware update process (e.g. USB DFU front-end)

Having this application will make it possible to implement device features that are not practical to expose via the local device UI, and can be used as an aid to the manufacturing calibration process.

Ideally, this application should also be implemented with a cross-platform framework (e.g. Qt), and provide install/setup support for all platforms. However, the initial goal is to just get something in place that's usable to support firmware/device development.

Closed 2022-03-17.

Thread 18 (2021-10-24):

Switch the USB connector from Micro-B to USB Type-C

dkonigsberg, 2021-10-24:
The USB connector currently being used for power and control is of the [Micro-B](https://en.wikipedia.org/wiki/USB_hardware#Micro_connectors) design. This is easy to work with, and quite common, but it is no longer the modern standard for new devices.

Since the underlying device is still only USB 2.0 Full Speed, we can probably get away with taking a simple approach to this.

Some notes about making this sort of change:

- They make simple connectors that only break out the pins relevant to USB 2.0
- ST app note [AN5225](https://www.st.com/resource/en/application_note/an5225-usb-typec-power-delivery-using-stm32-mcus-and-mpus-stmicroelectronics.pdf) shows a simple configuration where the DP and DN lines are tied together, and CC1/CC2 have 5.1k pull-down resistors. Taking this approach would be very easy and not require additional hardware of relevance.
- Can also use ICs like the [UTC2000](https://www.microchip.com/en-us/product/UTC2000) and [USB3740](https://www.microchip.com/wwwproducts/en/USB3740) to switch between pairs intelligently, but this would add cost and likely be of no real benefit
- The USB shell/shield should be grounded, regardless of how USB-C is implemented.  I've seen opinions both ways on whether or not this should be done on the device side. However, the majority of real world devices I've tested have shells connected to device ground.

Also note that the interface cannot be called "USB-C" or "USB Type-C" in the documentation without paying licensing fees to [USB-IF](https://www.usb.org/sites/default/files/usb_type-c_language_product_and_packaging_guidelines_final.pdf).  As such, any product documentation will continue to simply refer to the connector as either "USB" or "Compatible with USB-C®".

Closed 2022-01-05.

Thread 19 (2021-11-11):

Improve implementation of "zero'ing" readings for desktop interaction

dkonigsberg, 2021-11-11:
The way the process of zero'ing a reflection or transmission reading currently works, is by a button sequence that calls a function in the firmware that simply sets the current reading as the active offset.
This works fine for standalone device usage, but doesn't really interact cleanly with the desktop app.

The way this is implemented on device should be changed to a function that explicitly sets an offset, even if the button sequence still just sets it to the last reading.  Then a series of command API functions can be called for the purpose of getting and setting this value directly. The presence of this offset should also be incorporated into the "extended" format for reporting readings via the the USB-CDC interface.

Once these pieces are in place, the desktop app should be updated to both show the presence of the "zero" offset and to be able to change its value.

Closed 2022-03-22.

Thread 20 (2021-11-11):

Panelize the PCBs

dkonigsberg, 2021-11-11:
For manufacturing, the project PCBs need to be panelized. While that is something that could end up being done by the project itself or the PCB manufacturer, the project should go through the exercise to make sure the desired results can be achieved.

This involves two major steps, likely done in tandem:

1. Make any changes to the PCB outlines necessary to support panelization. This might, at most, involve adding a flatted section to the semi-circle edge on the left side of the main board.
2. Add scripts, likely based on [KiKit](https://github.com/yaqwsx/KiKit), to create panel projects that meed desired characteristics.  The panel projects themselves probably should not be checked in, but the execution of the script and any supporting steps should be.

[Small Batch Assembly](https://www.smallbatchassembly.com/faq/#What-about-PC-Board-Panelization-) recommends a maximum panel size of 216x290mm (8.5 x 11.5in)
Another possible assembler requests 290x190mm'ish, with 5mm rails, and 2mm NPTH for indexing and fiducials everywhere.

There might end up being more than one implementation of the panelization process, and there is likely to be some back-and-forth with the assembler to finalize things.

Closed 2022-03-17.

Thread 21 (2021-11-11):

Switch MCU to from STM32L072KBU6 to STM32L072KZT6

dkonigsberg, 2021-11-11:
The current MCU has 128k of Flash, 20kb of RAM, and comes in a UFQFPN32 (5x5mm) package.

The replacement MCU has 192kb of Flash, 20kb of RAM, and comes in a LQFP32 (7x7mm) package.

Otherwise, they should be almost equivalent.

This change is being driven entirely by the ongoing semiconductor component shortage.  While everything in the STM32L072x product line is basically out of stock with long and/or uncertain lead times, one vendor has admitted to having a large batch of the STM32L072KZT6 part on order and expected to arrive within a couple months. Switching packages will require some PCB layout changes, and switching parts will add a little bit to the BOM cost. However, the price increase is tiny in comparison to the total.

One benefit of the change is more flash, which will make it possible to use less code size optimization in the bootloader, and in the firmware itself, which will make debugging and feature addition a bit easier.

Closed 2022-01-05.

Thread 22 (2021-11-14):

Update main board LED footprints

dkonigsberg, 2021-11-14:
Based on the LED footprint change implemented in 9851340418bfb13fbbd49bb30c915e6bca7cbed2 in an effort to resolve #14, the footprints for the LEDs on the main board should be changed as well. Its less necessary there, due to the lower drive current, but still not a bad idea.

Most likely this will involve having two versions of the LED footprint in use within the project:

1. Transmission board LED footprint (9851340418bfb13fbbd49bb30c915e6bca7cbed2) that maximizes heat sinking by having copper on both sides of the PCB connected by vias.
2. Main board LED footprint that just adds the "H" pattern to the thermal pad, without going through the PCB. This is to avoid cutting ground and power planes below the LED, which exist on the main board but not on the transmission board.

Doing this cleanly could involve some footprint naming changes that update the metadata of the Rev B transmission PCB, but shouldn't have any effect on its actual design or layout. As such, its revision code is unlikely to change.

Closed 2021-11-30.

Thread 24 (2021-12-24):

Upgrade hardware projects from KiCad v5 to v6

dkonigsberg, 2021-12-24:
The release of [KiCad](https://www.kicad.org/) v6 imminent, and it will be easier to upgrade than to stick with v5 from here on out. As such, the hardware projects and associated libraries should be carefully upgraded to the new version.

This is going to involve widespread renaming of various KiCad files, so it is important to pay attention to which files are new and which ones are old. Some library conventions might change too, but that is optional.

As part of this upgrade, it may also make sense to start using certain new features (like variable replacement in silkscreen text, if available) where possible.

Closed 2022-01-04.

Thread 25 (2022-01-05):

Ensure desired hardware behavior when firmware hasn't started

dkonigsberg, 2022-01-05:
When the microcontroller firmware has not started up, or has started using a system bootloader (e.g. USB DFU), most of its GPIO pins (except SWCLK and SWDIO) may be set to an analog input mode. In this mode, things connected to them without external pull-up/pull-down resistors may float and have undesired behavior.

To make sure all the corner cases are covered, this situation should be dealt with:
- The `TLED_EN` and `RLED_EN` nets most likely need pull-down resistors. Without these, the LEDs may turn on at full power if the firmware hasn't been able to configure the GPIOs. Bench testing should be done to determine the exact behavior, and the appropriate resistor values to use.
- The OLED reset pin may need to be pulled to a known state. Most official examples do not show anything between the MCU and this pin, but some 3rd party breakout boards include a reset supervisory circuit.  Regardless, it may take some bench testing to determine whether or not this pin needs extra handling.

dkonigsberg, 2022-01-05:
### LED Driver Pins
It turns out that the real reason the LEDs were turning on at full power in system bootloader mode was not due to floating pins. Rather, it was due to the behavior of the STM bootloader as documented in [AN2606](https://www.st.com/resource/en/application_note/cd00167594-stm32-microcontroller-system-memory-boot-mode-stmicroelectronics.pdf). When the bootloader is running, USART1, USART2, and USB peripherals are all enabled. The pins used for `TLED_EN` and `RLED_EN` are the same pins respectively used for `USART2_RX` and `USART2_TX`. As such, they were being deliberately driven high.

Thus, there are two options:
1. Ignore the problem, because the bootloader isn't triggered as part of normal operation
2. Switch the LED driver `EN` pins to `PB3 (TIM2_CH2)` and `PA15 (TIM2_CH1)`, and reroute accordingly.

Additionally, as the AP2502 LED driver won't turn on unless its `EN` pin is above 2V, adding pull-downs is probably unnecessary. However, adding 10k pulldowns anyways, simply as a matter of extra precaution, is likely a good idea.

### OLED Display Reset Pin
I have not found any examples of boards using this kind of display with any sort of pull-down on the RESET pin. However, bench testing has shown that adding a 10k pulldown resistor to it is probably also a good idea. This is because:
1. After disconnecting a wire from this pin, it can take a few moments for the display to turn off. Monitoring this case with an oscilloscope shows this signal meandering downwards, due to capacitance of the system.
2. Adding a pull-down makes the trailing edge a lot sharper and cleaner, especially in various restart/unconfigured cases.

Closed 2022-01-06.

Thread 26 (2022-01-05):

Add bulk capacitor to VBUS input

dkonigsberg, 2022-01-05:
Right now the only capacitors on the VBUS +5V rail are a 1uF cap at the input to the 3.3V LDO and a few 0.1uF caps near the LED drivers.
There should probably also be a 4.7uF bulk capacitor near the input. Double-check other designs for examples of what's in common use, and add something.

Closed 2022-01-06.

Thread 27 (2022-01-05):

Clean up schematic and PCB layout to remove net ties

dkonigsberg, 2022-01-05:
The schematic, and by extension the PCB layout, uses net ties on certain display connector pins and LED driver pins for the sole purpose of making KiCad's ERC happy. This adds extra cruft and confusion and should probably be eliminated.

Change the symbols for the display connector and the LED drivers so that net ties are not required, and then remove them. Electrically, this change should have no effect.

Closed 2022-01-06.

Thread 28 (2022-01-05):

Add notes to the schematic indicating which display module is in use

dkonigsberg, 2022-01-05:
The display would normally be considered part of the non-PCB BOM kept outside of KiCad, but the display connector makes little sense without knowing what it is.  At the very least, a note should be added to the schematic (and possibly the PCB layout) indicting what display is being used.

Closed 2022-01-06.

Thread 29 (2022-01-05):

Test USB suspend condition and ensure it can be correctly handled

dkonigsberg, 2022-01-05:
When the device is running off a USB port that has been suspended, its power budget likely drops to 2.5mA.
Do some testing to ensure this can be detected, and handled gracefully. With any luck, dealing with this will be entirely a firmware-level problem.

Actually testing this case will either require a utility that can directly exercise control over a USB port's power management behavior, or a laptop that can be easily brought in and out of suspend to stimulate the condition.

Once testing is complete, this task can be closed and replaced with tasks specific to whatever work needs to be done.

dkonigsberg, 2022-01-08:
There is some brief documentation in Section 31.5.5 of [RM0376](https://www.st.com/resource/en/reference_manual/dm00108281-ultralowpower-stm32l0x2-advanced-armbased-32bit-mcus-stmicroelectronics.pdf) about how USB suspend mode is handled from the perspective of the USB peripheral.

Also, the [HID_Standalone_LPM](https://github.com/STMicroelectronics/STM32CubeL0/tree/master/Projects/STM32L073Z-EVAL/Applications/USB_Device/HID_Standalone_LPM) example looks like it could be a useful reference for handling this stuff.

Regardless, at this stage the most important thing is to simply characterize device power consumption when all the peripherals are turned off and its placed in a low power mode. Doing this with scratch code, and capturing the results here, is sufficient to satisfy this task.

dkonigsberg, 2022-01-09:
Power bench tests on a Rev B prototype had the following results through normal use cases:
- System (DFU) Bootloader (Screen off, all LEDs full power) - 118mA
- Normal idle (Screen on, all LEDs off) - 22mA
- Reflection LED idle (Screen on, RLED low power) - 39mA
- Transmission idle (Screen on, TLED low power) - 23.6mA
- Reflection measure (Screen on, RLED full power) - 100mA
- Transmission measure (Screen on, TLED full power) - 60.4mA

Turning off the display and LEDs brought power consumption down to around 11mA. Turning off all the peripherals brought it down to 9.7-9.9mA. Entering sleep mode only helped a little, bringing it to 8.9mA. Changing settings on the HSE clock was not tested.

Entering full standby mode, however, dropped power consumption all the way to 0.567mA. This is likely where we'll end up with a full USB LPM implementation, as its what the STM example appears to do. That level is acceptable, and well within the 2.5mA budget.

dkonigsberg, 2022-01-24:
Testing complete. Implementation will be part of #31.

Closed 2022-01-24.

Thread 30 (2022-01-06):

Update firmware to handle Rev C hardware

dkonigsberg, 2022-01-06:
The pre-production (Rev C) hardware has a few changes that will need firmware/bootloader updates. This task is a way to keep track of those items and can be updated as necessary.

Those items include:
- Update firmware/bootloader configuration to reflect MCU change (#21)
  - MCU name changes, which affects the name of some files
  - MCU memory map changes, to reflect an increase from 128kb of flash to 192kb of flash
  - Bootloader size should probably change from 16kb to 32kb, and LTO optimization can probably be turned off.
  - Firmware size can then change from 112kb to 160kb
  - Any hard-coded addresses in the code, or build configurations, need to be adjusted to reflect these changes
- Update firmware to reflect LED enable pin change (#25)
  - `RLED_EN` changes from `PA2 (TIM2_CH3)` to `PB3 (TIM2_CH2)`
  - `TLED_EN` changes from `PA3 (TIM2_CH4)` to `PA15 (TIM2_CH1)`

Closed 2022-02-04.

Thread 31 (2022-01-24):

Implement support for USB suspend/resume

dkonigsberg, 2022-01-24:
### Overview
USB devices are supposed to support a "suspend" mode, where their power consumption drops to under 2.5mA.

Preliminary testing, as described in #29, showed that normal power consumption is around 20-120mA. However, shutting off all the peripherals and suspending the CPU will drop this to almost 0.5mA which is well within the suspend mode power budget.

Ideally, a device acting as a USB peripheral should be able to handle suspend, resume, and optionally remote wakeup of the host. Since being connected to a laptop that may suspend itself is an expected (albeit secondary) use case, suspend and resume should be correctly supported. Remote wakeup could also be implemented, but is less necessary or expected.

While the STM32L0 hardware does have the necessary support for implementing this, the [TinyUSB](https://github.com/hathach/tinyusb) device stack does not have a functional implementation in the STM32 port.

There is some brief documentation in Section 31.5.5 of [RM0376](https://www.st.com/resource/en/reference_manual/dm00108281-ultralowpower-stm32l0x2-advanced-armbased-32bit-mcus-stmicroelectronics.pdf) about how USB suspend mode is handled from the perspective of the USB peripheral.

Also, the [HID_Standalone_LPM](https://github.com/STMicroelectronics/STM32CubeL0/tree/master/Projects/STM32L073Z-EVAL/Applications/USB_Device/HID_Standalone_LPM) example looks like it could be a useful reference for handling this case.

### Development/Test Rig
In order to test these modes directly, the most practical approach is a rig consisting of the following components:
1. Laptop with USB 2.0 (EHCI ports, running the [USB-IF Compliance Tools](https://www.usb.org/compliancetools#anchor_ehcitools), which provide a direct way to stimulate various port behaviors. This is best kept as a dedicated machine, which does not depend on the USB controller used for its ports to run its local keyboard and mouse.
2. USB 2.0 hub connected to the laptop, to ensure that the laptop using an EHCI driver for its USB port regardless of how our device would otherwise show up. ("USB 2.0 Full-Speed" is kinda a marketing rename of USB 1.1, and such will bind to a UHCI device without this trick.)
3. USB power and/or protocol analyzer, to make it easy to see when USB traffic should indicate a state change and to directly monitor device current consumption in response to it. (This could be anything from a USB current monitor to a full-blown special-purpose test device.)
4. The actual device-under-test, a Printalyzer Densitometer prototype, connected to the development workstation via a debug probe.

### Implementation Notes
Since TinyUSB does not depend on HAL components for controlling the USB peripheral, some investigation will be needed to ensure that the code enables whatever device features get turned out when the following boxes are checked in CubeMX:
- USB -> Low Power
- USB -> Link Power Management

Some tracing through normal behaviors with HAL, the ST USB device stack, and the above-mentioned example, will be necessary to determine what changes must be made to the application code and/or TinyUSB's STM32 port to make all of this work.

Since suspend could be requested at any moment, there needs to be a way to trigger a "stop and drop everything" behavior for the application's main state machine so that all peripheral hardware can be turned off prior to suspending the CPU. Resume will be coming from a more known state, but could easily have its own share of issues.

One important gotcha is that we still need to deal with the watchdog timer (IWDG) when in suspend mode. For development, it probably makes sense to simply turn this off inside the bootloader. However, once working like this, we need to come up with a way of managing it without being disabled.

Closed 2022-02-08.

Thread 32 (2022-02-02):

Fix STM32 Unique ID handling code

dkonigsberg, 2022-02-02:
The Unique ID on the STM32L072 series being used in the project consists of three 32-bit words, starting at 0x1FF80050.
The problem is that these words are not contiguous. They're at offsets 0x00, 0x04, and 0x12.

Any code that uses this value needs to be fixed. Perhaps using the HAL wrapper functions could bury this weirdness a little better as well.

Closed 2022-02-04.

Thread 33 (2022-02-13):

Improve sensor gain calibration process

dkonigsberg, 2022-02-13:
The sensor gain calibration process, as currently implemented, runs entirely on device and is reachable via the calibration menu. It works by taking pairs of measurements at different gain settings, and calculation their relationship.

There are a few problems with the current approach:
- Its debatable whether this process should be exposed via the local UI, and its easy to do it wrong if you don't read instructions carefully. (e.g. device should be held tightly closed and left untouched throughout)
- Hard-coded magic numbers are used to control transmission LED brightness, to avoid sensor saturation during maximum gain calibration
- Some would argue that PWM-controlled LED brightness should never be used for this purpose, even if data so far suggests it may be okay

An argument can be made that this particular calibration step should be driven entirely by the desktop software, possibly even as part of a "factory calibration" routine, to prevent users from accidentally messing it up.

Furthermore, those magic numbers should be removed one of two ways:
1. By implementing some sort of automated level detection process to pick the right brightness value
2. By rewriting the process to require use of a step wedge instead of variable LED brightness

If changing this process to use a step wedge, then it should probably work like this:
- For each patch on the step wedge, hold down the measurement head and take transmission readings at every gain setting.
- Collect all the data in a table, and search it for comparable pairs.
- Calculate the measured gain values from those pairs.
(This approach would likely be much easier for someone to do from the desktop software, due to collection of data from multiple steps.)

dkonigsberg, 2022-03-17:
This task is probably done, for all intents and purposes. However, there's still an open question as to whether the trigger for this process should be on-device or only via the desktop app.
Given that this is part of the "factory" calibration process, and unlikely to be re-done regularly, it might make sense to move the trigger to the desktop app just to prevent users from doing it accidentally and messing up the device readings.

Closed 2022-03-22.

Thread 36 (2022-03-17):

Desktop application needs to be able to backup/restore device configuration data

dkonigsberg, 2022-03-17:
There is a lot of calibration data that ultimately ends up in the device's EEPROM, and there should be a way to back it up.
The "Configuration" tab of the desktop app should have a way of saving all of these numbers to a configuration file. It should also be able to restore this data from such a file.

Additionally, there should be support for "sparse" files, and some guardrails in place to prevent the overwriting of "manufacturing" calibration data by accident.

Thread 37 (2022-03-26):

Modify sensor channel processing flow to just use CH0

dkonigsberg, 2022-03-26:
The TSL2591 sensor has two channels, CH0 and CH1. The CH0 spectrum is vaguely similar to the "visual" density spectrum we are trying to measure, and the CH1 spectrum has lower sensitivity and leans towards the infrared.

The current approach subtracts the reading of CH1 from CH0, in basic counts, to get a combined reading that then has a slope correction applied and density calculations performed. So far this has worked out fine, despite some comments that combining sensor channels like this is not advisable.

However, recent analysis efforts have shown that CH1 has behavior that may not be desirable:
- Its log error characteristic curve, the thing slope correction exists to deal with, is completely different from CH0.
- Its thermal response curve (temperature-vs-reading) looks different from CH0, with a steeper slope
- Above 30C it introduces substantial "dark" reading errors, which cause issues on high density targets

For the most part, its been easy to ignore these issues because:
- The contribution of CH1 to the final reading is usually very small
- Most testing has occurred under room temperature conditions
- Measurement errors related to spectrum mismatch, as can happen with color targets, are more likely to be on the blue side of CH0. Meanwhile, CH1 only sees on the red side.

Making this change would only have a minor effect on the device's spectral sensitivity:
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

As such, making this change is likely a "safe" course of action for standardizing how the device processes sensor data.  For the most part, it would involve removing one math operation from a few routines and recalibrating the device.  It would also be possible to remove CH1 from the gain calibration data, however it does no harm to leave that in there.

Closed 2022-03-28.

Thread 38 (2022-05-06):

Device goes into low power mode when restarting after a firmware update

dkonigsberg, 2022-05-06:
This issue has been observed on Linux. It has not yet been tested on macOS or Windows, but should be.

When installing a firmware update via the UF2 bootloader, and then restarting into the new firmware image, the device immediately goes into low power mode.  This can easily be recovered from by unplugging/replugging the device, and the manual will recommend this just in case. However, this step should not be necessary.

A guess is that something happening on the USB interface is misinterpreted as a trigger for low power mode, however further investigation is needed.  Its possible that a fix could involve a special case for a post-update startup.

dkonigsberg, 2022-05-12:
So far this was not reproducible on macOS, but the log messages when it happens with a Linux host are a bit concerning:
```
I/task_main [       376 main] Starting controller loop
I/state_controller [       382 main] State transition: 15 -> 0
I/state_controller [       389 main] State transition: 0 -> 1
D/task_main [       898 usbd] tud_suspend_cb
I/state_controller [       930 main] Notify switch to state: 14
I/state_controller [       937 main] State transition: 1 -> 14
D/task_main [       944 usbd] tud_resume_cb
I/state_suspend [       949 main] Entering suspend state
D/task_sensor [       956 sensor] sensor_control_stop
```
This pretty much suggests that its a race condition when suspend and resume events happen too close together, so the relationship to firmware updates could only be coincidental.  This means its a higher priority issue to resolve.

Closed 2022-05-12.

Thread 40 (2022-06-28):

Add settings for the measurement LED idle states

dkonigsberg, 2022-06-28:
The measurement LEDs have a low-brightness "idle" state used to help the user align a target to be measured.
Currently, this state is only triggered when the "detect" switch notices the device is pressed part-way closed.

A user suggestion is to make it possible for the idle illumination to be configurable in the following ways:
- Add an option for the light to come on for a longer period of time, with a configurable timeout
- Make the brightness of the idle illumination configurable (this would help with higher density transmission targets)

To support this, first a series of experiments must be conducted to determine the effect of any change here on full-brightness readings. This would be similar to the experiments conducted to track LED brightness-vs-on-time, only more specific to the variable involved in adding these settings.

dkonigsberg, 2022-07-01:
Initial testing across a range of targets has shown that its most likely safe to allow a range of configurable brightness ranges, with the limit at 25% for transmission and 50% for reflection.
The defaults for this setting should be chosen to correspond to the current brightness values.

dkonigsberg, 2022-07-11:
This feature should now be implemented.
e2b7db45620bd4a951d8dd67251a510ae67ff6fb
7e48157993cac658aef524fe1b989b851524f415
af2adc05549f2b03e18e03b3ce75b1fab45f3af6
a2a6b5217b50710b226d80393abd50ded298a557

Closed 2022-07-11.

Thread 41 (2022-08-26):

Select a larger TVS diode for single-line protection

dkonigsberg, 2022-08-26:
This issue should be investigated prior to a second manufacturing batch, but is not an urgent problem for the time being.

All of the single-line ESD protection cases on the main board are currently using the ST [ESDALC6V1-1M2](https://www.st.com/en/protections-and-emi-filters/esdalc6v1-1m2.html) TVS diode.  The problem with this diode, is that while it has a similar outline as an 0402 component, its design makes it behave like it is much smaller in practice.  As such, it is difficult to work with and has been causing assembly headaches.

Hopefully a replacement component can be found of identical/similar specs, with a larger and easier to work with footprint, that's easy to stick into the design without any notable changes otherwise.

dkonigsberg, 2022-08-27:
Just did a review of all the pins currently protected by single-line TVS diodes, with the following results:

| Label | Pin   | Type |
| ------| ----- | ---- |
| BTN1  | PA1   | FT   |
| BTN2  | PA0   | TTa  |
| BTN3  | PC15  | TC   |
| BTN4  | PC14  | FT   |
| BTN5  | PA8   | FTf  |
| -     | BOOT0 | -    |
| -     | NRST  | -    |

Based on the datasheet, the following tolerances are assumed:

- **FT** and **FTf**: V<sub>DD</sub>+4.0 => 7.3V (5V tolerant)
- **TTa**: Similar to TC, used in its place in other datasheets and app notes
- **TC**: 4.0V (standard 3.3V I/O)
- **BOOT0**: V<sub>DD</sub>+4.0 => 7.3V
- **NRST**: Unclear, but given how dev boards protect it we can hopefully assume its the same as BOOT0 and FT/FTf

The TVS diode currently being used to protect all of these lines has a V<sub>BR</sub> of 6.1V.

The L-series datasheets list the absolute maximum rating of the TC/TT pins at 4.0V, while some older app notes claim 3.6V (V<sub>DD</sub>+0.3V).  Not taking this into account was a design oversight, however, it is highly unlikely that the top-of-device buttons will conduct well enough to ever experience an ESD problem.  In fact, in lab tests, the **only** part of the device that ever arced was the shield on the USB connector.

That being said, it would be advisable that any replacement 1-line TVS diode opt for a V<sub>BR</sub> in the 3.6-4.0V range.

dkonigsberg, 2023-01-14:
Reopening because the uClamp3301H has side effects that make it a no-go for this use case.

Should switch to the uClamp0501H and hope there are no events across BTN3, or find a different TVS diode in a similar footprint with a 3.3V working voltage.

Closed 2023-02-10.

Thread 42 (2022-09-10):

Change paste layer settings to optimize on a per-component level

dkonigsberg, 2022-09-10:
The current paste layer has every component specifying 100% copper pad coverage, with a global -5% paste relative clearance across the board.  According to manufacturing feedback and evaluation, this is not ideal. While it helps on the fine pitch components, it results in not enough paste on the pads of other components.

What should be done, prior to any future assembly runs, is a change where the global paste clearance is set back to the default of zero.  Then, per-component and per-pad clearance settings should be applied where needed.  This may result in a lot of footprint customization, but I think we're already using custom footprints for most of the affected parts anyways.

Initial suggestions from the assembler are:
- Paste aperture can remain at 100% of copper for pads with > ~.8mm pitch
- For pads < ~.8mm a good rule of thumb is to shrink by ~33%
- For big single thermal pads underneath also shrink by ~50%
- The FPC connector (J3) with those long pins is one in particular need of such attention

Its as of yet unclear how these percentages are determined, as they do not match KiCad's relative clearance logic. However, once that's figured out, sensible values will be applied.

Closed 2022-11-28.

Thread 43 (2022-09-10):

Fix origin of ER-CON30HT-1 (J3) footprint

dkonigsberg, 2022-09-10:
For some reason, this footprint's origin is smack dab in the middle of its pins.  For positioning data to make a bit more sense, and hopefully require a bit less tuning, move this origin to the center of the component body.

Just be careful to avoid any actual component position changes when making this update, which will require footprint and PCB layout changes to be made in coordination.  If done right, this should result in no visible change to the PCB itself and only changes to the position data files.

*Note: This wasn't requested by the PCB assembler, but is something that's been bugging me ever since preparing the position files for assembly.*

Closed 2022-11-28.

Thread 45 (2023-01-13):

Target calibration should validate parameters consistent with calibration checks on measurement

dkonigsberg, 2023-01-13:
It is possible for a user to fumble the target calibration process, and successfully save invalid calibration parameters.  They'll then encounter an "Invalid calibration" error when trying to take a measurement.

This can be most easily reproduced by doing a reflection calibration, then measuring the CAL-HI patch before the CAL-LO patch.  The calibration routine does not check the relationship of these readings, but the measurement/settings-get routing does.

Closed 2023-06-13.

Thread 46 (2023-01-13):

CRC module is not correctly initialized in the firmware

dkonigsberg, 2023-01-13:
The bootloader uses the CRC module to verify the firmware image, and this part is working perfectly.  However, the main firmware itself does not correctly reinitialize the CRC module when it starts up.  As a result, any calls to calculate the CRC of data from within the firmware return zero.

There is extensive code related to the EEPROM settings storage that's designed to use CRC to verify the integrity of calibration data against corruption.  As of now, this code is not accomplishing anything.

**It is very important that any effort to fix this bug should also increment the version of any EEPROM settings pages using CRC and populate the CRC values as part of that upgrade. If this is not done very carefully, it could invalidate factory calibration on any devices that install code that re-enables the CRC module.**

For now, it is very low priority to fix this.  The risk of not detecting corrupted calibration data is, as of this time, considered much lower than the risk of invalidating existing calibration data as part of a firmware upgrade.  This issue is mostly being written for reference purposes.

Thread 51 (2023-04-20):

Add ability to change the decimal separator

dkonigsberg, 2023-04-20:
The densitometer's firmware does not currently support any sort of localization.  For local device usage, this is not a big problem. However, when bringing readings into a computer, it can become an issue.  Most notably is the case of the decimal separator, which can be either a period or a comma depending on the user's country.

Making it possible to change the separator character is probably a good idea, pending some decisions as to the following details:

- Should this affect the local device display, or just the USB interface?
- If this affects the local device, should it take effect everywhere (i.e. configuration menus) or just on the main reading display?
- Should this be a global setting, or just a format option for the USB Key Output?

dkonigsberg, 2023-06-13:
Task completed in fw-1.1.0

Closed 2023-06-13.

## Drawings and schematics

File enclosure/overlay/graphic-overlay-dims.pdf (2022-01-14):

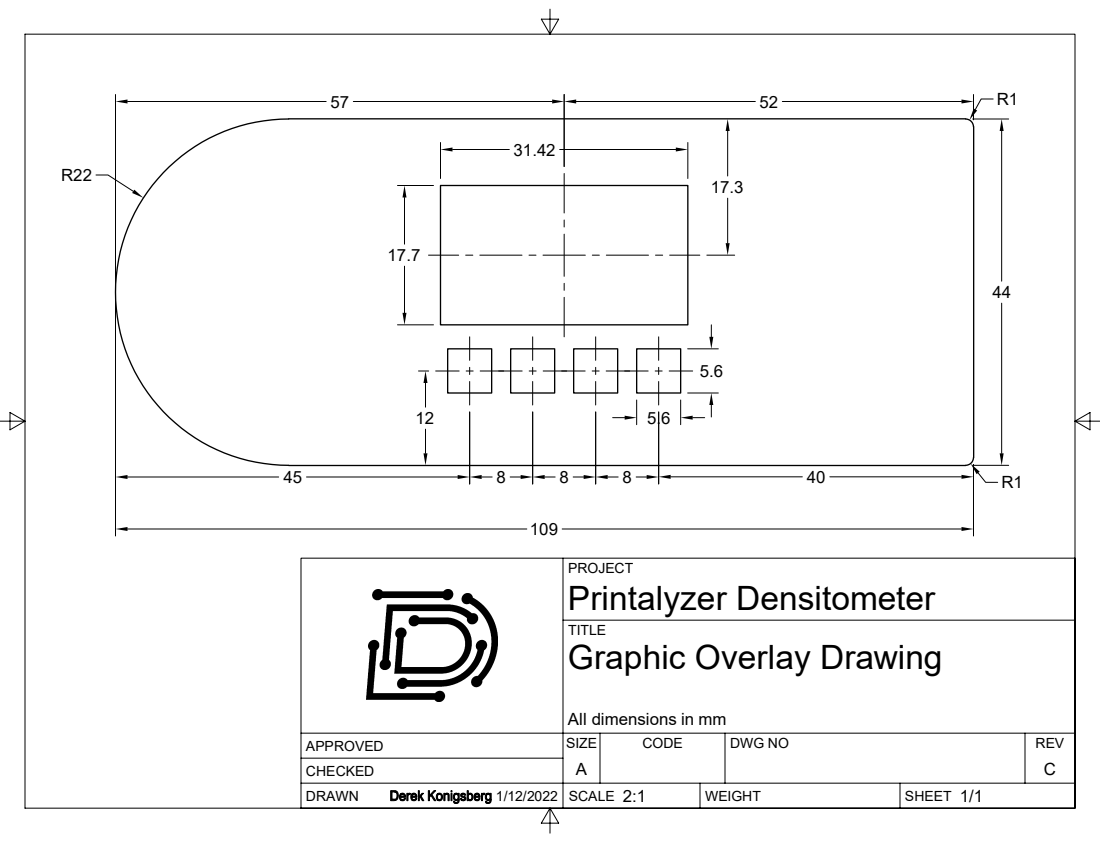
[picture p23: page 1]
PROJECT TITLE DRAWN CHECKED APPROVED; SCALE; WEIGHT; SHEET SIZE; CODE; DWG NO; REV 1/12/2022; C Printalyzer Densitometer All dimensions in mm Graphic Overlay Drawing

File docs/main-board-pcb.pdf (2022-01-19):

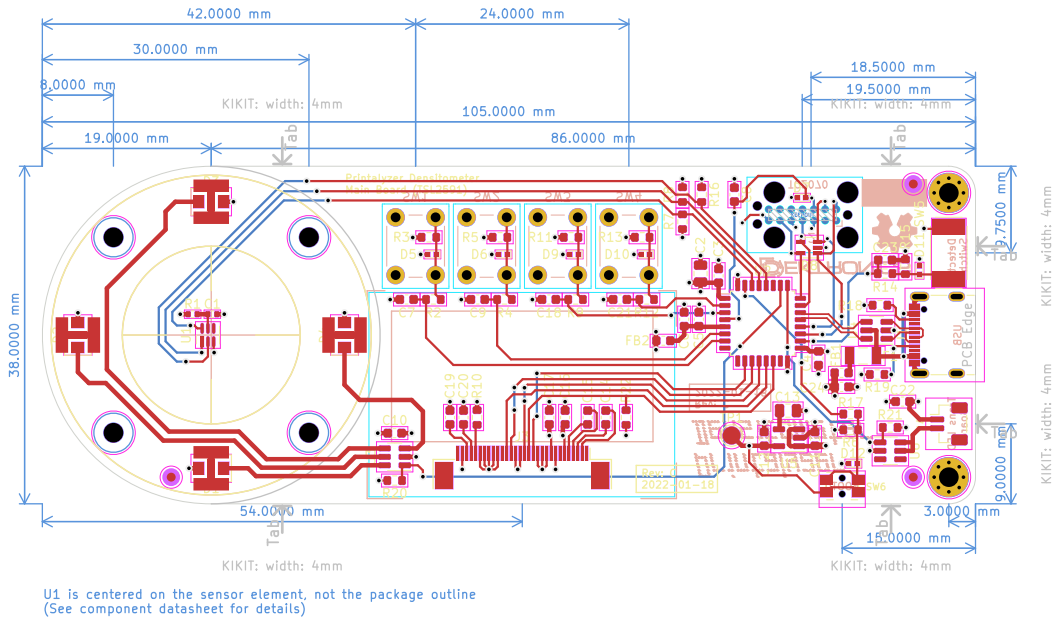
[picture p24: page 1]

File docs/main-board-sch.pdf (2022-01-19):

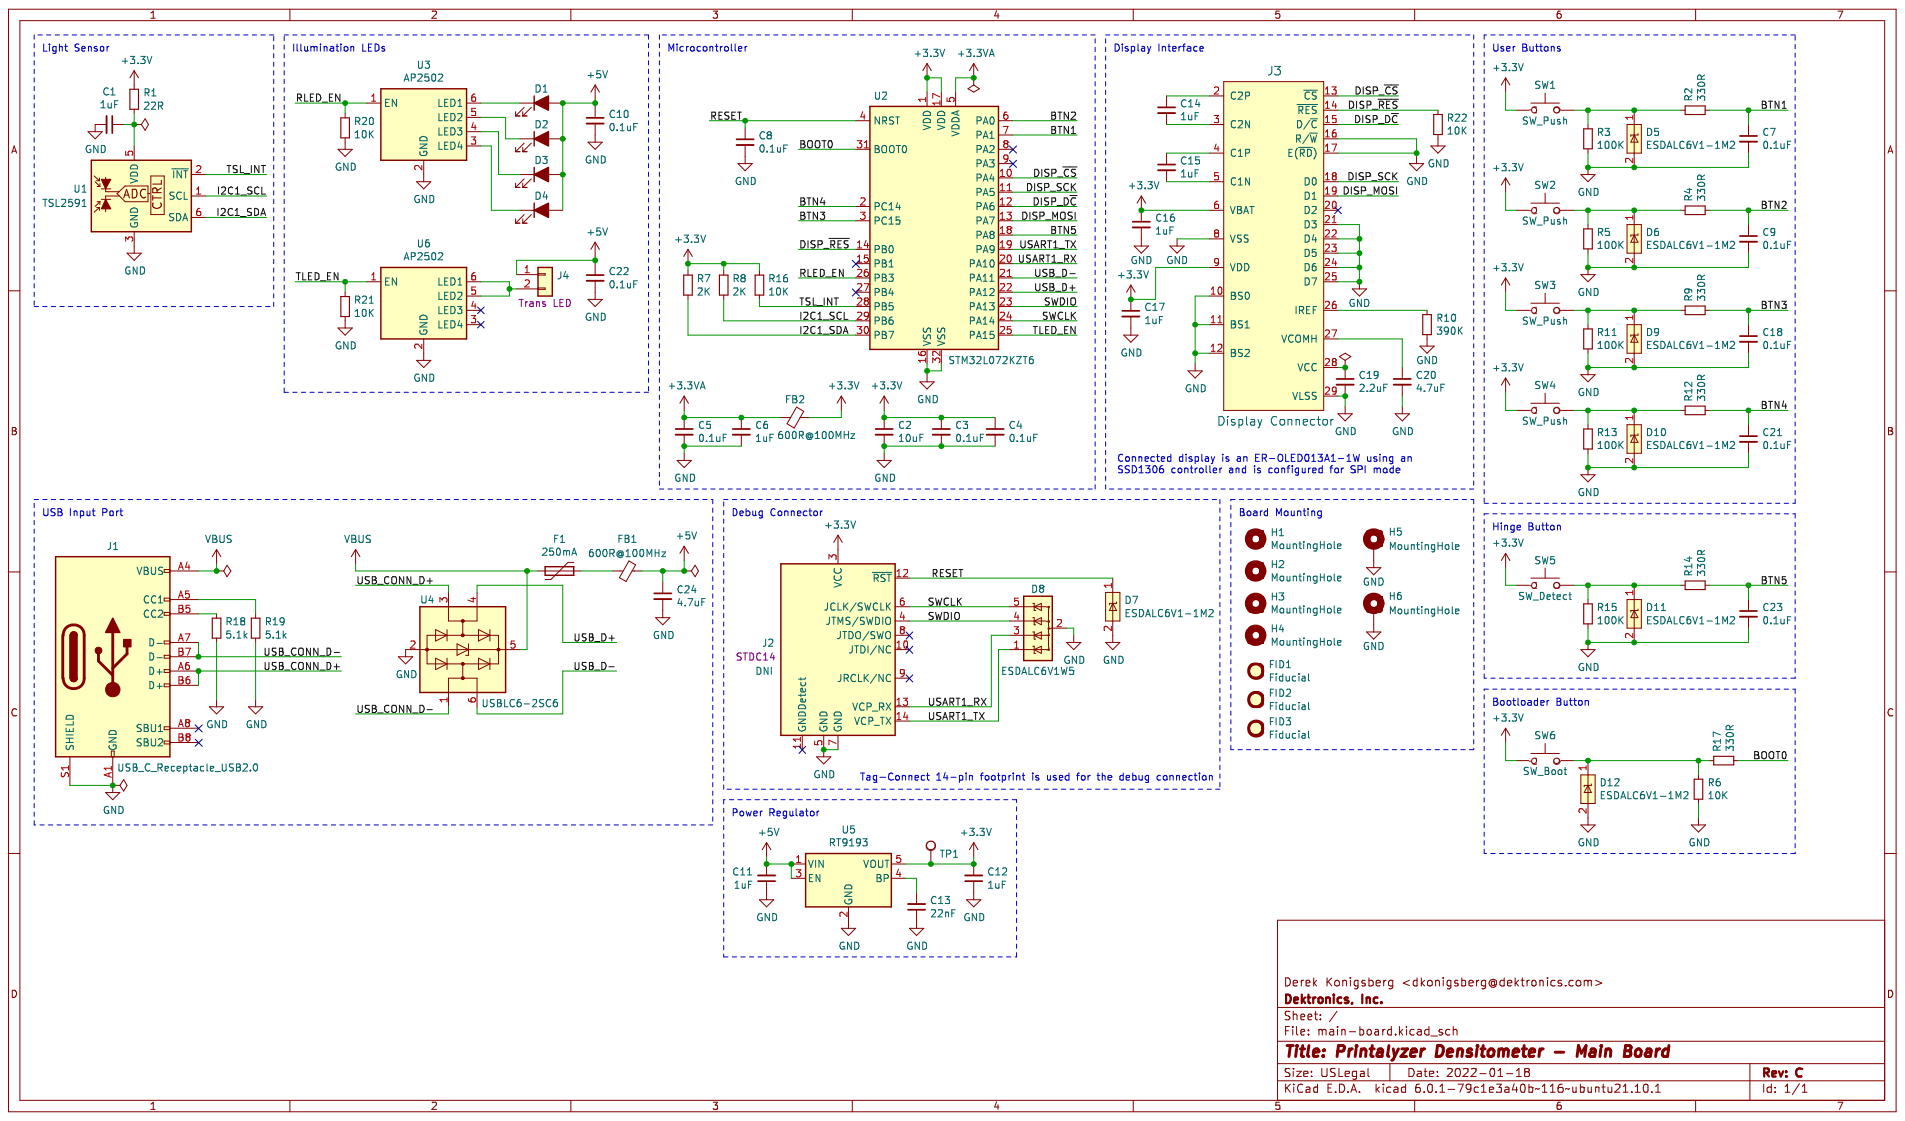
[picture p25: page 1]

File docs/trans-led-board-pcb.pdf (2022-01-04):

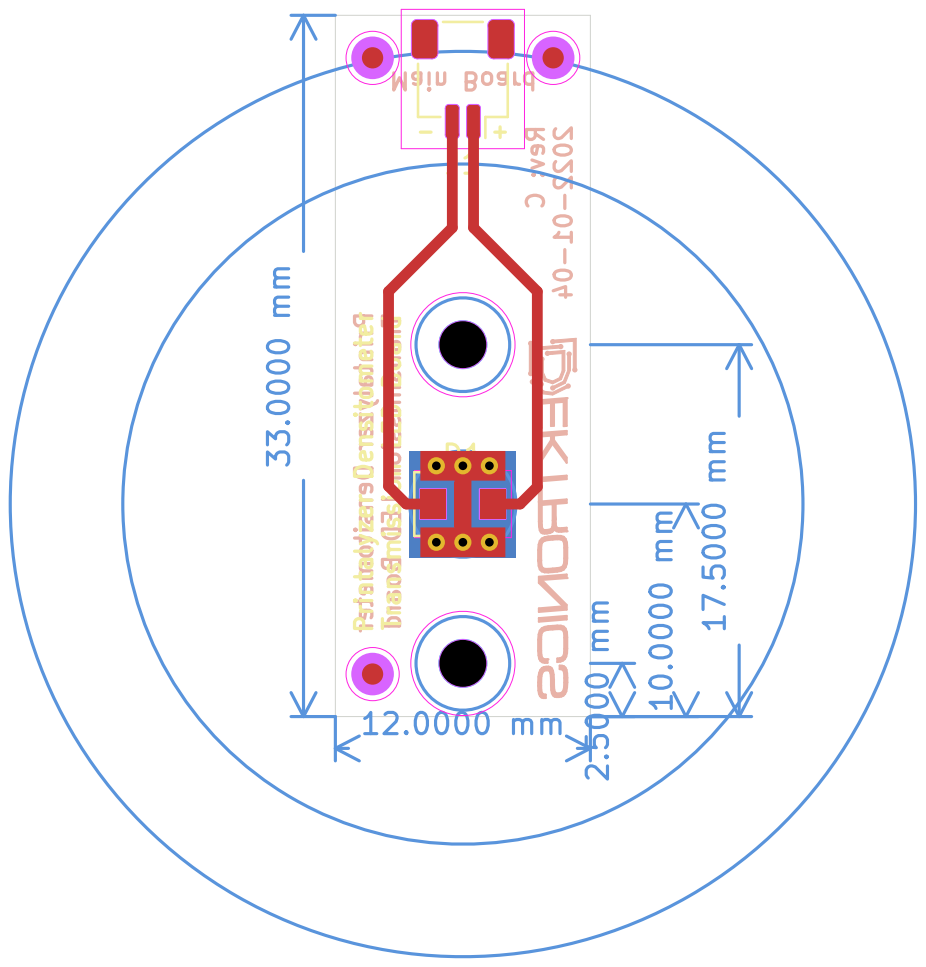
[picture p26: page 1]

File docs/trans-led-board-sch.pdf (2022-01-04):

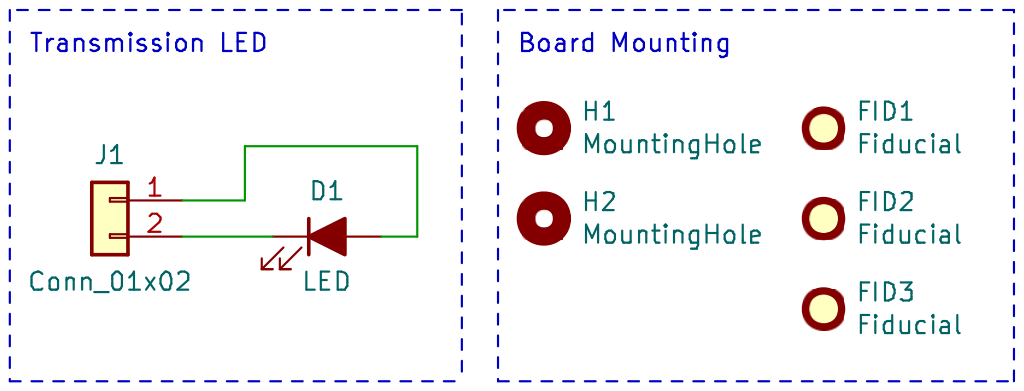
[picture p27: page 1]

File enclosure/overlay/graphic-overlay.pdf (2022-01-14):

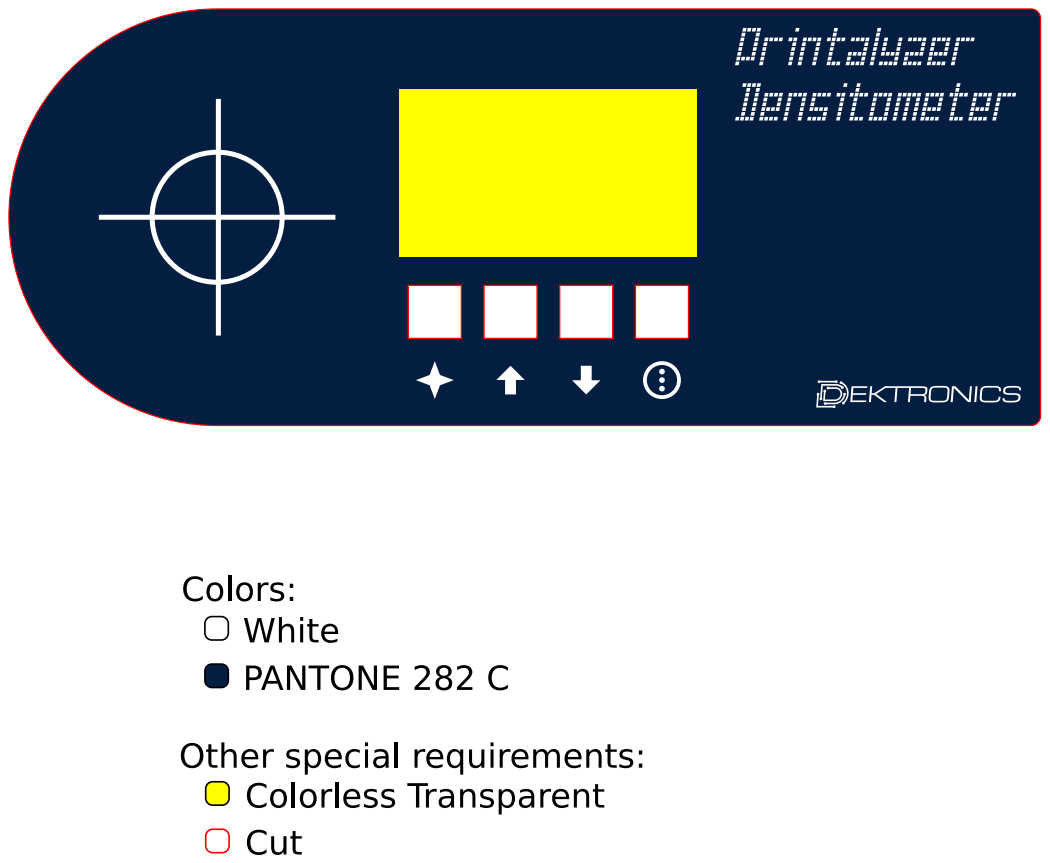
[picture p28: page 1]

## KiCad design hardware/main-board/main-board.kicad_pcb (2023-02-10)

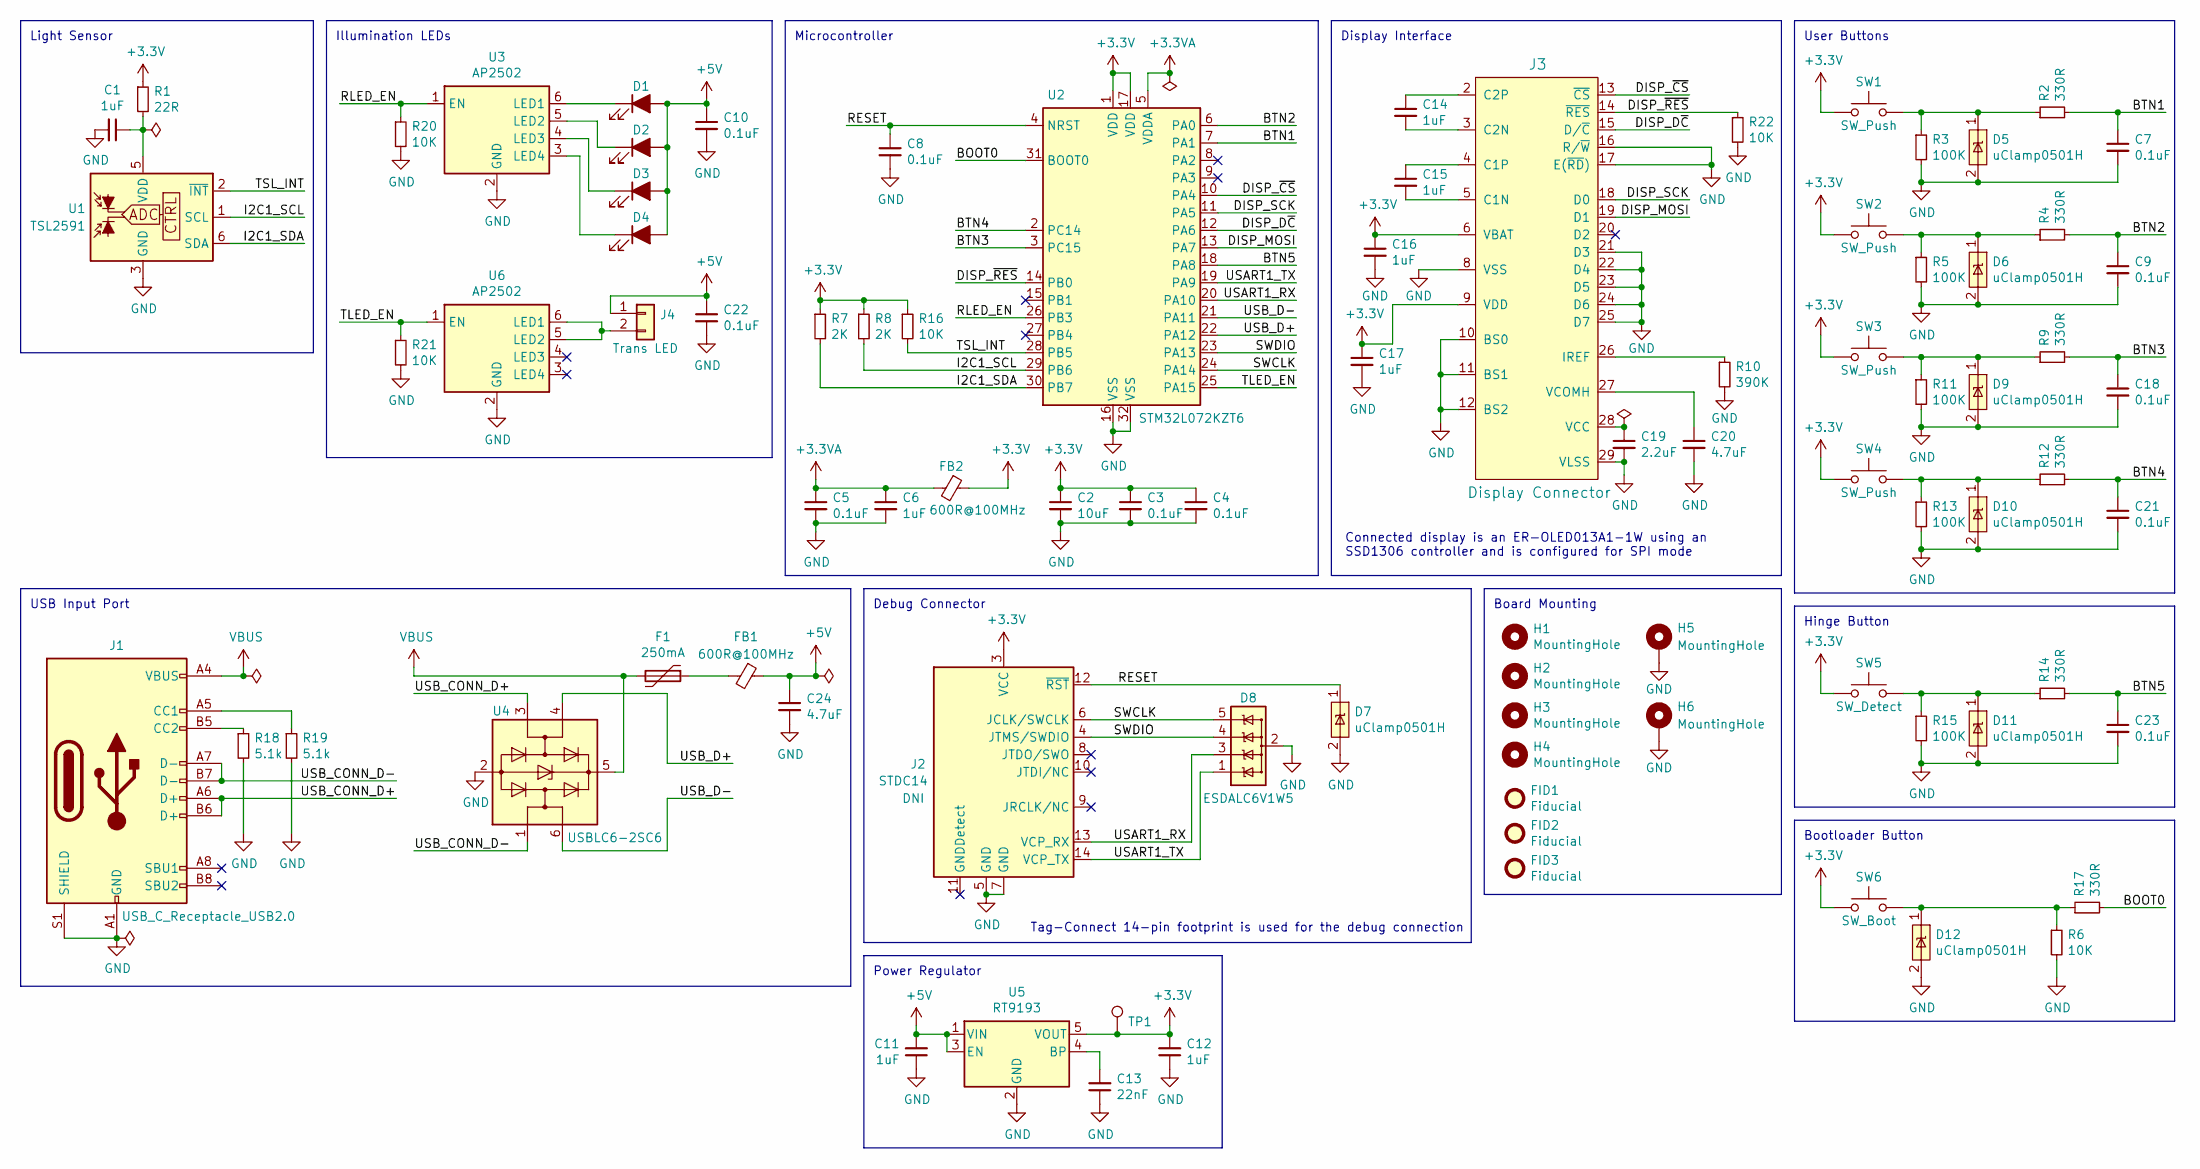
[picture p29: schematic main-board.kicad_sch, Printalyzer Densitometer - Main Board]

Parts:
C1: 1uF; C_0402_1005Metric; Manufacturer PN CL05A105KQ5NNNC
C2: 10uF; C_0805_2012Metric; Manufacturer PN CL21A106KAYNNNE
C3, C4, C5, C7, C8, C9, C10, C18, C21, C22, C23: 0.1uF; C_0603_1608Metric; Manufacturer PN CL10B104KA8NNNC
C6, C11, C12, C14, C15, C16, C17: 1uF; C_0603_1608Metric; Manufacturer PN CL10B105KA8NNNC
C13: 22nF; C_0805_2012Metric; Manufacturer PN C2012C0G1H223JT000N
C19: 2.2uF; C_0603_1608Metric; Manufacturer PN CL10B225KP8NNNC
C20, C24: 4.7uF; C_0603_1608Metric; Manufacturer PN CL10A475KA8NQNC
D1, D2, D3, D4: LED; LED_WL-SWTP-3022-1MP; Manufacturer PN 158302250
D5, D6, D7, D9, D10, D11, D12: uClamp0501H; D_SOD-523; Manufacturer PN UCLAMP0501H.TCT
D8: ESDALC6V1W5; SOT323-5L; Manufacturer PN ESDALC6V1W5
F1: 250mA; BF_0ZCJ_1206; Manufacturer PN 1206L025YR
FB1, FB2: 600R@100MHz; L_0603_1608Metric; Manufacturer PN MMZ1608B601CTAH0
FID1, FID2, FID3: Fiducial; Fiducial_1mm_Mask2mm
H1, H2, H3, H4: MountingHole; MountingHole_2.2mm_M2
H5, H6: MountingHole; MountingHole_2.2mm_M2_Pad_Via
J1: USB_C_Receptacle_USB2.0; USB_C_Receptacle_GCT_USB4105; Manufacturer PN USB4105-GF-A
J2: DNI; Tag-Connect_TC2070-IDC-FP_2x07_P1.27mm_Vertical; Manufacturer PN TC2070-IDC-050
J3: Display Connector; ER-CON30HT-1; Manufacturer PN ER-CON30HT-1
J4: Conn_01x02; JST_SH_BM02B-SRSS-TB_1x02-1MP_P1.00mm_Vertical; Manufacturer PN BM02B-SRSS-TB(LF)(SN)
R1: 22R; R_0402_1005Metric; Manufacturer PN AC0402JR-0722RL
R2, R4, R9, R12, R14, R17: 330R; R_0603_1608Metric; Manufacturer PN RC0603JR-07330RL
R3, R5, R11, R13, R15: 100K; R_0603_1608Metric; Manufacturer PN RC0603JR-07100KL
R6, R16, R20, R21, R22: 10K; R_0603_1608Metric; Manufacturer PN RC0603JR-0710KL
R7, R8: 2K; R_0603_1608Metric; Manufacturer PN CRCW06032K00JNEA
R10: 390K; R_0603_1608Metric; Manufacturer PN RC0603FR-07390KL
R18, R19: 5.1k; R_0603_1608Metric; Manufacturer PN RC0603JR-075K1L
SW1, SW2, SW3, SW4: SW_Push; ESwitch_TL1105_6mm_H7.5mm; Manufacturer PN TL1105SPF160Q
SW5: SW_Detect; CK_KSU213WLFG; Manufacturer PN KSU213WLFG
SW6: SW_Boot; Panasonic_EVQP7C_EVQP7L; Manufacturer PN EVQ-P7L01P
TP1: 3.3V; TestPoint_Pad_D2.0mm
U1: TSL2591; AMS_TSL2591; Manufacturer PN TSL25911FN
U2: STM32L072KZT6; ST_LQFP32; Manufacturer PN STM32L072KZT6
U3, U6: AP2502; SOT-23-6; Manufacturer PN AP2502KTR-G1
U4: USBLC6-2SC6; SOT-23-6; Manufacturer PN USBLC6-2SC6
U5: RT9193; SOT-23-5; Manufacturer PN RT9193-33GB

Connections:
+3.3V: C2.1, C3.1, C4.1, C12.2, C16.1, C17.1, FB2.1, J2.3 (VCC), J3.6 (VBAT), J3.9 (VDD), R1.1, R7.1, R8.1, R16.1, SW1.1, SW2.1, SW3.1, SW4.1, SW5.1, SW6.1, TP1.1, U2.1 (VDD), U2.17 (VDD), U5.5 (VOUT)
+3.3VA: C5.1, C6.1, FB2.2, U2.5 (VDDA)
+5V: C10.1, C11.2, C22.1, C24.1, D1.2 (A), D2.2 (A), D3.2 (A), D4.2 (A), FB1.1, J4.1, U5.1 (VIN), U5.3 (EN)
/BOOT0: R17.2, U2.31 (BOOT0)
/BTN1: C7.1, R2.2, U2.7 (PA1)
/BTN2: C9.1, R4.2, U2.6 (PA0)
/BTN3: C18.1, R9.2, U2.3 (PC15)
/BTN4: C21.1, R12.2, U2.2 (PC14)
/BTN5: C23.1, R14.2, U2.18 (PA8)
/DISP_D~C: J3.15 (D/~C), U2.12 (PA6)
/DISP_MOSI: J3.19 (D1), U2.13 (PA7)
/DISP_SCK: J3.18 (D0), U2.11 (PA5)
/DISP_~CS: J3.13 (~CS), U2.10 (PA4)
/DISP_~RES: J3.14 (~RES), R22.1, U2.14 (PB0)
/I2C1_SCL: R8.2, U1.1 (SCL), U2.29 (PB6)
/I2C1_SDA: R7.2, U1.6 (SDA), U2.30 (PB7)
/RESET: C8.1, D7.1 (IO1), J2.12 (~RST), U2.4 (NRST)
/RLED_EN: R20.1, U2.26 (PB3), U3.1 (EN)
/SWCLK: D8.5 (IO4), J2.6 (JCLK/SWCLK), U2.24 (PA14)
/SWDIO: D8.4 (IO3), J2.4 (JTMS/SWDIO), U2.23 (PA13)
/TLED_EN: R21.1, U2.25 (PA15), U6.1 (EN)
/TSL_INT: R16.2, U1.2 (~INT), U2.28 (PB5)
/USART1_RX: D8.3 (IO2), J2.13 (VCP_RX), U2.20 (PA10)
/USART1_TX: D8.1 (IO1), J2.14 (VCP_TX), U2.19 (PA9)
/USB_CONN_D+: J1.A6 (D+), J1.B6 (D+), U4.3 (I/O2)
/USB_CONN_D-: J1.A7 (D-), J1.B7 (D-), U4.1 (I/O1)
/USB_D+: U2.22 (PA12), U4.4 (I/O2)
/USB_D-: U2.21 (PA11), U4.6 (I/O1)
GND: C1.2, C2.2, C3.2, C4.2, C5.2, C6.2, C7.2, C8.2, C9.2, C10.2, C11.1, C12.1, C13.1, C16.2, C17.2, C18.2, C19.2, C20.2, C21.2, C22.2, C23.2, C24.2, D5.2 (GND), D6.2 (GND), D7.2 (GND), D8.2 (GND), D9.2 (GND), D10.2 (GND), D11.2 (GND), D12.2 (GND), H5.1, H6.1, J1.A1 (GND), J1.A12 (GND), J1.B1 (GND), J1.B12 (GND), J1.S1 (SHIELD), J2.5 (GND), J2.7 (GND), J3.8 (VSS), J3.10 (BS0), J3.11 (BS1), J3.12 (BS2), J3.16 (R/~W), J3.17 (E(~RD)), J3.21 (D3), J3.22 (D4), J3.23 (D5), J3.24 (D6), J3.25 (D7), J3.29 (VLSS), R3.2, R5.2, R6.2, R10.2, R11.2, R13.2, R15.2, R18.2, R19.2, R20.2, R21.2, R22.2, U1.3 (GND), U2.16 (VSS), U2.32 (VSS), U3.2 (GND), U4.2 (GND), U5.2 (GND), U6.2 (GND)
unnamed: C1.1, R1.2, U1.5 (VDD)
unnamed: C13.2, U5.4 (BP)
unnamed: C14.1, J3.2 (C2P)
unnamed: C14.2, J3.3 (C2N)
unnamed: C15.1, J3.4 (C1P)
unnamed: C15.2, J3.5 (C1N)
unnamed: C19.1, J3.28 (VCC)
unnamed: C20.1, J3.27 (VCOMH)
unnamed: D1.1 (K), U3.6 (LED1)
unnamed: D2.1 (K), U3.5 (LED2)
unnamed: D3.1 (K), U3.4 (LED3)
unnamed: D4.1 (K), U3.3 (LED4)
unnamed: D5.1 (IO1), R2.1, R3.1, SW1.2
unnamed: D6.1 (IO1), R4.1, R5.1, SW2.2
unnamed: D9.1 (IO1), R9.1, R11.1, SW3.2
unnamed: D10.1 (IO1), R12.1, R13.1, SW4.2
unnamed: D11.1 (IO1), R14.1, R15.1, SW5.2
unnamed: D12.1 (IO1), R6.1, R17.1, SW6.2
unnamed: F1.1, FB1.2
unnamed: J1.A5 (CC1), R19.1
unnamed: J1.B5 (CC2), R18.1
unnamed: J3.26 (IREF), R10.1
unnamed: J4.2, U6.5 (LED2), U6.6 (LED1)
VBUS: F1.2, J1.A4 (VBUS), J1.A9 (VBUS), J1.B4 (VBUS), J1.B9 (VBUS), U4.5 (VBUS)

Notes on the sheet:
Board Mounting
Illumination LEDs
Tag-Connect 14-pin footprint is used for the debug connection
Power Regulator
Display Interface
Debug Connector
USB Input Port
Bootloader Button
Light Sensor
User Buttons
Connected display is an ER-OLED013A1-1W using an SSD1306 controller and is configured for SPI mode
Microcontroller
Hinge Button

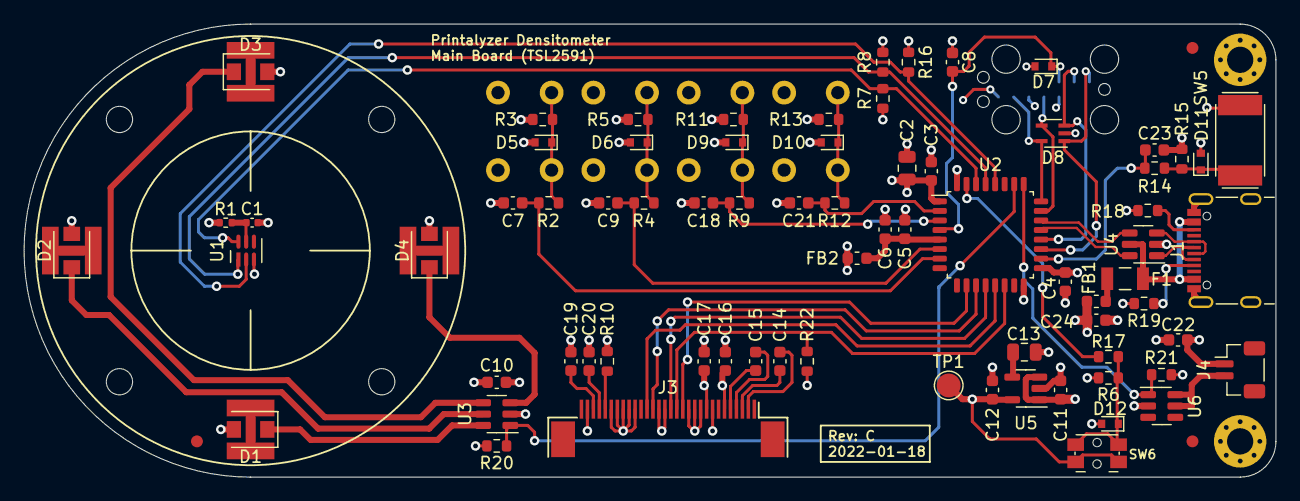
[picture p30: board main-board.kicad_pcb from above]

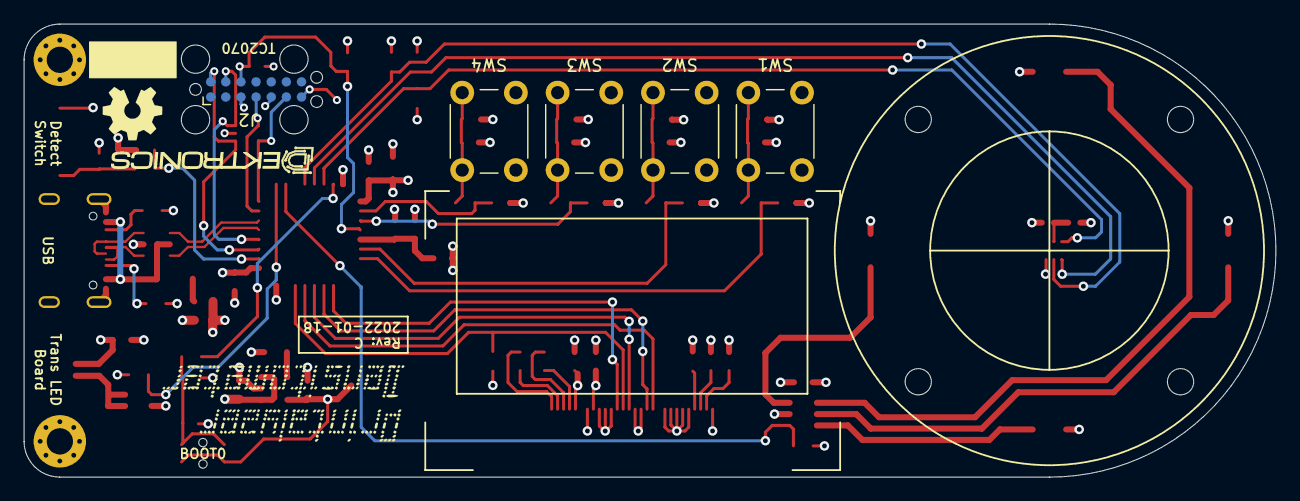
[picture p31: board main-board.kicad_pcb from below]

Board: 4 copper layers, 105.0 x 38.0 mm, 96 parts (9 on the bottom side), 53 nets.

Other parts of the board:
G1: LOGO; Printalyzer-logo-16_9mm
G2: LOGO; densitometer-logo-16_9mm
G4: OSHW-logo_5mm
LOGO: G3; Dektronics-logo
REF1, REF2, REF4, REF5, REF6: Tab

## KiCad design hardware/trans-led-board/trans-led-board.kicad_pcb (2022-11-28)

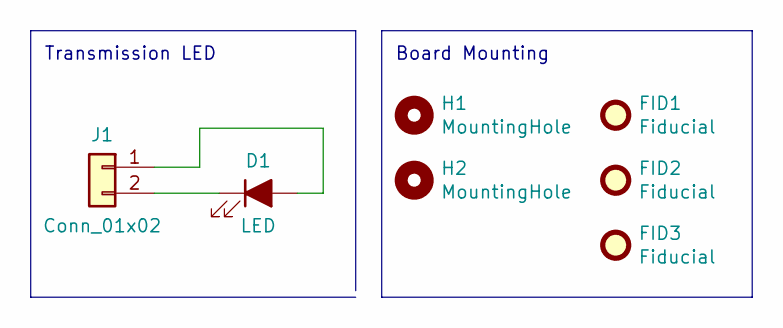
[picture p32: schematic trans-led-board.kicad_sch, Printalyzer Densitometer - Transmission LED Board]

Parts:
D1: LED; LED_WL-SWTP-3022-1MP_ThermalVias; Manufacturer PN 158302250
FID1, FID2, FID3: Fiducial; Fiducial_1mm_Mask2mm
H1, H2: MountingHole; MountingHole_2.2mm_M2
J1: Conn_01x02; JST_SH_SM02B-SRSS-TB_1x02-1MP_P1.00mm_Horizontal; Manufacturer PN SM02B-SRSS-TB(LF)(SN)

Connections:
unnamed: D1.1 (K), J1.2
unnamed: D1.2 (A), J1.1

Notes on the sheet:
Board Mounting
Transmission LED

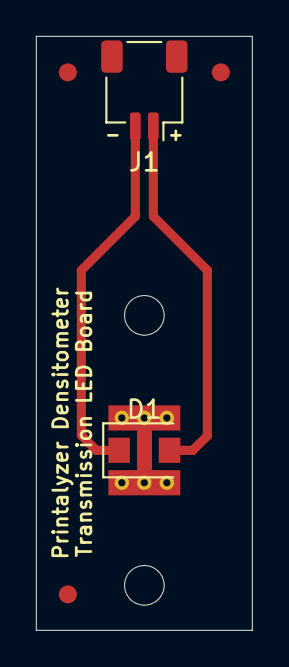
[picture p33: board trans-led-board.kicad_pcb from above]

Board: 2 copper layers, 12.0 x 33.0 mm, 8 parts (1 on the bottom side), 2 nets.

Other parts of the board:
LOGO: G1; Dektronics-logo

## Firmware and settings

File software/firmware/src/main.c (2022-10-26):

#include "main.h"
#include "stm32l0xx_hal.h"

#define LOG_TAG "main"
#include <elog.h>

#include <printf.h>
#include <cmsis_os.h>
#include <machine/endian.h>

#include "board_config.h"
#include "keypad.h"
#include "sensor.h"
#include "display.h"
#include "adc_handler.h"
#include "task_main.h"
#include "task_sensor.h"
#include "app_descriptor.h"
#include "state_suspend.h"
#include "util.h"

#ifdef HAL_IWDG_MODULE_ENABLED
IWDG_HandleTypeDef hiwdg;
#endif
CRC_HandleTypeDef hcrc;
RTC_HandleTypeDef hrtc;
ADC_HandleTypeDef hadc;
DMA_HandleTypeDef hdma_adc;
I2C_HandleTypeDef hi2c1;
SPI_HandleTypeDef hspi1;
TIM_HandleTypeDef htim2;
UART_HandleTypeDef huart1;

static uint32_t startup_bkp0r = 0;

static void read_startup_flags(void);
static void iwdg_init(void);
static void rtc_init(void);
static void usart1_uart_init(void);
static void logger_init(void);
static void gpio_init(void);
static void i2c1_init(void);
static void tim2_init(void);
static void spi1_init(void);
static void crc_init(void);
static void dma_init(void);
static void adc_init(void);
static void usb_init(void);
static void startup_log_messages(void);

void usb_device_task(void *argument);
void cdc_task_func(void *argument);

void error_handler(void);
void HAL_TIM_MspPostInit(TIM_HandleTypeDef *htim);

void system_clock_config(void)
{
    RCC_OscInitTypeDef RCC_OscInitStruct = {0};
    RCC_ClkInitTypeDef RCC_ClkInitStruct = {0};
    RCC_PeriphCLKInitTypeDef PeriphClkInit = {0};

    /* Configure the main internal regulator output voltage */
    __HAL_PWR_VOLTAGESCALING_CONFIG(PWR_REGULATOR_VOLTAGE_SCALE1);

    /*
     * Initialize the RCC Oscillators according to the specified parameters
     * in the RCC_OscInitTypeDef structure.
     */
    RCC_OscInitStruct.OscillatorType = RCC_OSCILLATORTYPE_HSI | RCC_OSCILLATORTYPE_LSI
        | RCC_OSCILLATORTYPE_HSI48;
    RCC_OscInitStruct.HSIState = RCC_HSI_ON;
    RCC_OscInitStruct.HSICalibrationValue = RCC_HSICALIBRATION_DEFAULT;
    RCC_OscInitStruct.LSIState = RCC_LSI_ON;
    RCC_OscInitStruct.HSI48State = RCC_HSI48_ON;
    RCC_OscInitStruct.PLL.PLLState = RCC_PLL_ON;
    RCC_OscInitStruct.PLL.PLLSource = RCC_PLLSOURCE_HSI;
    RCC_OscInitStruct.PLL.PLLMUL = RCC_PLLMUL_6;
    RCC_OscInitStruct.PLL.PLLDIV = RCC_PLLDIV_3;
    if (HAL_RCC_OscConfig(&RCC_OscInitStruct) != HAL_OK) {
        error_handler();
    }

    /* Initialize the CPU, AHB and APB buses clocks */
    RCC_ClkInitStruct.ClockType = RCC_CLOCKTYPE_HCLK | RCC_CLOCKTYPE_SYSCLK
        | RCC_CLOCKTYPE_PCLK1 | RCC_CLOCKTYPE_PCLK2;
    RCC_ClkInitStruct.SYSCLKSource = RCC_SYSCLKSOURCE_PLLCLK;
    RCC_ClkInitStruct.AHBCLKDivider = RCC_SYSCLK_DIV1;
    RCC_ClkInitStruct.APB1CLKDivider = RCC_HCLK_DIV1;
    RCC_ClkInitStruct.APB2CLKDivider = RCC_HCLK_DIV1;
    if (HAL_RCC_ClockConfig(&RCC_ClkInitStruct, FLASH_LATENCY_1) != HAL_OK) {
        error_handler();
    }

    PeriphClkInit.PeriphClockSelection = RCC_PERIPHCLK_USART1 | RCC_PERIPHCLK_I2C1
        | RCC_PERIPHCLK_RTC | RCC_PERIPHCLK_USB;
    PeriphClkInit.Usart1ClockSelection = RCC_USART1CLKSOURCE_PCLK2;
    PeriphClkInit.I2c1ClockSelection = RCC_I2C1CLKSOURCE_PCLK1;
    PeriphClkInit.RTCClockSelection = RCC_RTCCLKSOURCE_LSI;
    PeriphClkInit.UsbClockSelection = RCC_USBCLKSOURCE_HSI48;
    if (HAL_RCCEx_PeriphCLKConfig(&PeriphClkInit) != HAL_OK) {
        error_handler();
    }
}

void read_startup_flags(void)
{
    /*
     * Startup flags are stored in the RTC backup domain registers.
     * Since the backup domain is configured as part of the system
     * clock configuration that occurs prior to this function,
     * it should be left alone here.
     */

    startup_bkp0r = RTC->BKP0R;
    RTC->BKP0R = 0;

    if (startup_bkp0r == 0) {
        startup_bkp0r = RCC->CSR & 0xFF000000UL;
    }
}

void iwdg_init(void)
{
#ifdef HAL_IWDG_MODULE_ENABLED
    hiwdg.Instance = IWDG;
    hiwdg.Init.Prescaler = IWDG_PRESCALER_4;
    hiwdg.Init.Window = 4095;
    hiwdg.Init.Reload = 4095;
    if (HAL_IWDG_Init(&hiwdg) != HAL_OK) {
        error_handler();
    }
    __HAL_RCC_DBGMCU_CLK_ENABLE();
    __HAL_DBGMCU_FREEZE_IWDG();
#endif
}

void rtc_init(void)
{
    /* Initialize RTC Only */
    hrtc.Instance = RTC;
    hrtc.Init.HourFormat = RTC_HOURFORMAT_24;
    hrtc.Init.AsynchPrediv = 127;
    hrtc.Init.SynchPrediv = 255;
    hrtc.Init.OutPut = RTC_OUTPUT_DISABLE;
    hrtc.Init.OutPutRemap = RTC_OUTPUT_REMAP_NONE;
    hrtc.Init.OutPutPolarity = RTC_OUTPUT_POLARITY_HIGH;
    hrtc.Init.OutPutType = RTC_OUTPUT_TYPE_OPENDRAIN;
    if (HAL_RTC_Init(&hrtc) != HAL_OK) {
        error_handler();
    }
}

void usart1_uart_init(void)
{
    huart1.Instance = USART1;
    huart1.Init.BaudRate = 115200;
    huart1.Init.WordLength = UART_WORDLENGTH_8B;
    huart1.Init.StopBits = UART_STOPBITS_1;
    huart1.Init.Parity = UART_PARITY_NONE;
    huart1.Init.Mode = UART_MODE_TX_RX;
    huart1.Init.HwFlowCtl = UART_HWCONTROL_NONE;
    huart1.Init.OverSampling = UART_OVERSAMPLING_16;
    huart1.Init.OneBitSampling = UART_ONE_BIT_SAMPLE_DISABLE;
    huart1.AdvancedInit.AdvFeatureInit = UART_ADVFEATURE_NO_INIT;
    if (HAL_UART_Init(&huart1) != HAL_OK) {
        error_handler();
    }
}

void logger_init(void)
{
    /* Initialize EasyLogger */
    elog_init();

    /* Set log format */
    elog_set_fmt(ELOG_LVL_ASSERT, ELOG_FMT_ALL);
    elog_set_fmt(ELOG_LVL_ERROR, ELOG_FMT_LVL | ELOG_FMT_TAG | ELOG_FMT_TIME | ELOG_FMT_T_INFO);
    elog_set_fmt(ELOG_LVL_WARN, ELOG_FMT_LVL | ELOG_FMT_TAG | ELOG_FMT_TIME | ELOG_FMT_T_INFO);
    elog_set_fmt(ELOG_LVL_INFO, ELOG_FMT_LVL | ELOG_FMT_TAG | ELOG_FMT_TIME | ELOG_FMT_T_INFO);
    elog_set_fmt(ELOG_LVL_DEBUG, ELOG_FMT_LVL | ELOG_FMT_TAG | ELOG_FMT_TIME | ELOG_FMT_T_INFO);
    elog_set_fmt(ELOG_LVL_VERBOSE, ELOG_FMT_ALL & ~(ELOG_FMT_FUNC | ELOG_FMT_T_INFO | ELOG_FMT_P_INFO));
    elog_set_text_color_enabled(true);

    /* Start EasyLogger */
    elog_start();
}

void gpio_button_config(void)
{
    GPIO_InitTypeDef GPIO_InitStruct = {0};

    /* Configure GPIO pins: BTN4_Pin BTN3_Pin */
    GPIO_InitStruct.Pin = BTN4_Pin | BTN3_Pin;
    GPIO_InitStruct.Mode = GPIO_MODE_IT_RISING_FALLING;
    GPIO_InitStruct.Pull = GPIO_NOPULL;
    HAL_GPIO_Init(GPIOC, &GPIO_InitStruct);

    /* Configure GPIO pins: BTN2_Pin BTN1_Pin BTN5_Pin */
    GPIO_InitStruct.Pin = BTN2_Pin | BTN1_Pin | BTN5_Pin;
    GPIO_InitStruct.Mode = GPIO_MODE_IT_RISING_FALLING;
    GPIO_InitStruct.Pull = GPIO_NOPULL;
    HAL_GPIO_Init(GPIOA, &GPIO_InitStruct);
}

void gpio_button_unconfig(void)
{
    GPIO_InitTypeDef GPIO_InitStruct = {0};

    /* Configure GPIO pins: BTN4_Pin BTN3_Pin */
    GPIO_InitStruct.Pin = BTN4_Pin | BTN3_Pin;
    GPIO_InitStruct.Mode = GPIO_MODE_ANALOG;
    HAL_GPIO_Init(GPIOC, &GPIO_InitStruct);

    /* Configure GPIO pins: BTN2_Pin BTN1_Pin BTN5_Pin */
    GPIO_InitStruct.Pin = BTN2_Pin | BTN1_Pin | BTN5_Pin;
    GPIO_InitStruct.Mode = GPIO_MODE_ANALOG;
    HAL_GPIO_Init(GPIOA, &GPIO_InitStruct);
}

void gpio_init(void)
{
    GPIO_InitTypeDef GPIO_InitStruct = {0};

    /* GPIO Ports Clock Enable */
    __HAL_RCC_GPIOC_CLK_ENABLE();
    __HAL_RCC_GPIOA_CLK_ENABLE();
    __HAL_RCC_GPIOB_CLK_ENABLE();

    /* Configure default GPIO pin output levels for the display */
    HAL_GPIO_WritePin(DISP_CS_GPIO_Port, DISP_CS_Pin, GPIO_PIN_SET);
    HAL_GPIO_WritePin(DISP_DC_GPIO_Port, DISP_DC_Pin, GPIO_PIN_RESET);
    HAL_GPIO_WritePin(DISP_RES_GPIO_Port, DISP_RES_Pin, GPIO_PIN_RESET);

    /* Configure GPIO pins for BTN[1..5] */
    gpio_button_config();

    /* Configure GPIO pins: PA2 PA3 */
    GPIO_InitStruct.Pin = GPIO_PIN_2 | GPIO_PIN_3;
    GPIO_InitStruct.Mode = GPIO_MODE_ANALOG;
    GPIO_InitStruct.Pull = GPIO_NOPULL;
    HAL_GPIO_Init(GPIOA, &GPIO_InitStruct);

    /* Configure GPIO pins: DISP_CS_Pin DISP_DC_Pin */
    GPIO_InitStruct.Pin = DISP_CS_Pin | DISP_DC_Pin;
    GPIO_InitStruct.Mode = GPIO_MODE_OUTPUT_PP;
    GPIO_InitStruct.Pull = GPIO_NOPULL;
    GPIO_InitStruct.Speed = GPIO_SPEED_FREQ_LOW;
    HAL_GPIO_Init(GPIOA, &GPIO_InitStruct);

    /* Configure GPIO pin: DISP_RES_Pin */
    GPIO_InitStruct.Pin = DISP_RES_Pin;
    GPIO_InitStruct.Mode = GPIO_MODE_OUTPUT_PP;
    GPIO_InitStruct.Pull = GPIO_NOPULL;
    GPIO_InitStruct.Speed = GPIO_SPEED_FREQ_LOW;
    HAL_GPIO_Init(DISP_RES_GPIO_Port, &GPIO_InitStruct);

    /* Configure unused GPIO pins: PB1 PB4 */
    GPIO_InitStruct.Pin = GPIO_PIN_1 | GPIO_PIN_4;
    GPIO_InitStruct.Mode = GPIO_MODE_ANALOG;
    GPIO_InitStruct.Pull = GPIO_NOPULL;
    HAL_GPIO_Init(GPIOB, &GPIO_InitStruct);

    /* Configure GPIO pin: SENSOR_INT_Pin */
    GPIO_InitStruct.Pin = SENSOR_INT_Pin;
    GPIO_InitStruct.Mode = GPIO_MODE_IT_FALLING;
    GPIO_InitStruct.Pull = GPIO_NOPULL;
    HAL_GPIO_Init(SENSOR_INT_GPIO_Port, &GPIO_InitStruct);

    /* EXTI interrupt init */
    HAL_NVIC_SetPriority(EXTI0_1_IRQn, 3, 0);
    HAL_NVIC_EnableIRQ(EXTI0_1_IRQn);
    HAL_NVIC_SetPriority(EXTI4_15_IRQn, 3, 0);
    HAL_NVIC_EnableIRQ(EXTI4_15_IRQn);
}

void i2c1_init(void)
{
    hi2c1.Instance = I2C1;

    /*
     * CubeMX calculated value for the following configuration:
     * - I2C Frequency: 400kHz
     * - Rise Time: 250ns
     * - Fall Time: 100ns
     * - Coefficient of Digital Filter: 0
     * - Analog Filter: Enabled
     */
    hi2c1.Init.Timing = 0x00B0122A;

    hi2c1.Init.OwnAddress1 = 0;
    hi2c1.Init.AddressingMode = I2C_ADDRESSINGMODE_7BIT;
    hi2c1.Init.DualAddressMode = I2C_DUALADDRESS_DISABLE;
    hi2c1.Init.OwnAddress2 = 0;
    hi2c1.Init.OwnAddress2Masks = I2C_OA2_NOMASK;
    hi2c1.Init.GeneralCallMode = I2C_GENERALCALL_DISABLE;
    hi2c1.Init.NoStretchMode = I2C_NOSTRETCH_DISABLE;

    if (HAL_I2C_Init(&hi2c1) != HAL_OK) {
        error_handler();
    }

    /* Configure analog filter */
    if (HAL_I2CEx_ConfigAnalogFilter(&hi2c1, I2C_ANALOGFILTER_ENABLE) != HAL_OK) {
        error_handler();
    }

    /* Configure digital filter */
    if (HAL_I2CEx_ConfigDigitalFilter(&hi2c1, 0) != HAL_OK) {
        error_handler();
    }
}

void tim2_init(void)
{
    /*
     * PWM frequency for LED drivers: 41.667kHz
     * This frequency was chosen to keep the timing of the output waveform
     * within the specifications of the LED driver, when the timer is set
     * to the maximum PWM duty cycle.
     */
    TIM_ClockConfigTypeDef sClockSourceConfig = {0};
    TIM_MasterConfigTypeDef sMasterConfig = {0};
    TIM_OC_InitTypeDef sConfigOC = {0};

    htim2.Instance = TIM2;
    htim2.Init.Prescaler = 5;
    htim2.Init.CounterMode = TIM_COUNTERMODE_UP;
    htim2.Init.Period = 127;
    htim2.Init.ClockDivision = TIM_CLOCKDIVISION_DIV1;
    htim2.Init.AutoReloadPreload = TIM_AUTORELOAD_PRELOAD_DISABLE;
    if (HAL_TIM_Base_Init(&htim2) != HAL_OK) {
        error_handler();
    }

    sClockSourceConfig.ClockSource = TIM_CLOCKSOURCE_INTERNAL;
    if (HAL_TIM_ConfigClockSource(&htim2, &sClockSourceConfig) != HAL_OK) {
        error_handler();
    }

    if (HAL_TIM_PWM_Init(&htim2) != HAL_OK) {
        error_handler();
    }

    sMasterConfig.MasterOutputTrigger = TIM_TRGO_RESET;
    sMasterConfig.MasterSlaveMode = TIM_MASTERSLAVEMODE_DISABLE;
    if (HAL_TIMEx_MasterConfigSynchronization(&htim2, &sMasterConfig) != HAL_OK) {
        error_handler();
    }

    sConfigOC.OCMode = TIM_OCMODE_PWM1;
    sConfigOC.Pulse = 64;
    sConfigOC.OCPolarity = TIM_OCPOLARITY_HIGH;
    sConfigOC.OCFastMode = TIM_OCFAST_DISABLE;
    if (HAL_TIM_PWM_ConfigChannel(&htim2, &sConfigOC, TIM_CHANNEL_1) != HAL_OK) {
        error_handler();
    }
    if (HAL_TIM_PWM_ConfigChannel(&htim2, &sConfigOC, TIM_CHANNEL_2) != HAL_OK) {
        error_handler();
    }

    HAL_TIM_MspPostInit(&htim2);
}

void spi1_init(void)
{
    hspi1.Instance = SPI1;
    hspi1.Init.Mode = SPI_MODE_MASTER;
    hspi1.Init.Direction = SPI_DIRECTION_2LINES;
    hspi1.Init.DataSize = SPI_DATASIZE_8BIT;
    hspi1.Init.CLKPolarity = SPI_POLARITY_LOW;
    hspi1.Init.CLKPhase = SPI_PHASE_1EDGE;
    hspi1.Init.NSS = SPI_NSS_SOFT;
    hspi1.Init.BaudRatePrescaler = SPI_BAUDRATEPRESCALER_2;
    hspi1.Init.FirstBit = SPI_FIRSTBIT_MSB;
    hspi1.Init.TIMode = SPI_TIMODE_DISABLE;
    hspi1.Init.CRCCalculation = SPI_CRCCALCULATION_DISABLE;
    hspi1.Init.CRCPolynomial = 7;
    if (HAL_SPI_Init(&hspi1) != HAL_OK) {
        error_handler();
    }
}

void crc_init(void)
{
    hcrc.Instance = CRC;
    hcrc.Init.DefaultPolynomialUse = DEFAULT_POLYNOMIAL_ENABLE;
    hcrc.Init.DefaultInitValueUse = DEFAULT_INIT_VALUE_ENABLE;
    hcrc.Init.InputDataInversionMode = CRC_INPUTDATA_INVERSION_NONE;
    hcrc.Init.OutputDataInversionMode = CRC_OUTPUTDATA_INVERSION_DISABLE;
    hcrc.InputDataFormat = CRC_INPUTDATA_FORMAT_WORDS;
    if (HAL_CRC_Init(&hcrc) != HAL_OK) {
        error_handler();
    }
}

void dma_init(void)
{
    /* DMA controller clock enable */
    __HAL_RCC_DMA1_CLK_ENABLE();

    /* DMA interrupt init */
    /* DMA1_Channel1_IRQn interrupt configuration */
    HAL_NVIC_SetPriority(DMA1_Channel1_IRQn, 3, 0);
    HAL_NVIC_EnableIRQ(DMA1_Channel1_IRQn);
}

void adc_init(void)
{
    ADC_ChannelConfTypeDef sConfig = {0};

    /*
     * Configure the global features of the ADC
     * (Clock, Resolution, Data Alignment and number of conversions)
     */
    hadc.Instance = ADC1;
    hadc.Init.OversamplingMode = ENABLE;
    hadc.Init.Oversample.Ratio = ADC_OVERSAMPLING_RATIO_16;
    hadc.Init.Oversample.RightBitShift = ADC_RIGHTBITSHIFT_NONE;
    hadc.Init.Oversample.TriggeredMode = ADC_TRIGGEREDMODE_SINGLE_TRIGGER;
    hadc.Init.ClockPrescaler = ADC_CLOCK_ASYNC_DIV1;
    hadc.Init.Resolution = ADC_RESOLUTION_12B;
    hadc.Init.SamplingTime = ADC_SAMPLETIME_160CYCLES_5;
    hadc.Init.ScanConvMode = ADC_SCAN_DIRECTION_FORWARD;
    hadc.Init.DataAlign = ADC_DATAALIGN_RIGHT;
    hadc.Init.ContinuousConvMode = ENABLE;
    hadc.Init.DiscontinuousConvMode = DISABLE;
    hadc.Init.ExternalTrigConvEdge = ADC_EXTERNALTRIGCONVEDGE_NONE;
    hadc.Init.ExternalTrigConv = ADC_SOFTWARE_START;
    hadc.Init.DMAContinuousRequests = ENABLE;
    hadc.Init.EOCSelection = ADC_EOC_SEQ_CONV;
    hadc.Init.Overrun = ADC_OVR_DATA_OVERWRITTEN;
    hadc.Init.LowPowerAutoWait = DISABLE;
    hadc.Init.LowPowerFrequencyMode = DISABLE;
    hadc.Init.LowPowerAutoPowerOff = DISABLE;
    if (HAL_ADC_Init(&hadc) != HAL_OK) {
        error_handler();
    }

    /*
     * Configure for the selected ADC regular channel to be converted.
     */
    sConfig.Channel = ADC_CHANNEL_TEMPSENSOR;
    sConfig.Rank = ADC_RANK_CHANNEL_NUMBER;
    if (HAL_ADC_ConfigChannel(&hadc, &sConfig) != HAL_OK) {
        error_handler();
    }

    /*
     * Configure for the selected ADC regular channel to be converted.
     */
    sConfig.Channel = ADC_CHANNEL_VREFINT;
    if (HAL_ADC_ConfigChannel(&hadc, &sConfig) != HAL_OK) {
        error_handler();
    }

    if (HAL_ADCEx_EnableVREFINT() != HAL_OK) {
        error_handler();
    }
    if (HAL_ADCEx_EnableVREFINTTempSensor() != HAL_OK) {
        error_handler();
    }
}

void usb_init(void)
{
    /* Peripheral clock enable */
    __HAL_RCC_USB_CLK_ENABLE();

    /* Peripheral interrupt init */
    HAL_NVIC_SetPriority(USB_IRQn, 3, 0);
}

void startup_log_messages(void)
{
    const app_descriptor_t *app_descriptor = app_descriptor_get();
    uint32_t hal_ver = HAL_GetHalVersion();
    uint8_t hal_ver_code = ((uint8_t)(hal_ver)) & 0x0F;
    uint16_t *flash_size = (uint16_t*)(FLASHSIZE_BASE);

    log_i("\033[0m");
    log_i("---- %s Startup ----", app_descriptor->project_name);
    log_i("HAL Version: %d.%d.%d%c",
        ((uint8_t)(hal_ver >> 24)) & 0x0F,
        ((uint8_t)(hal_ver >> 16)) & 0x0F,
        ((uint8_t)(hal_ver >> 8)) & 0x0F,
        hal_ver_code > 0 ? (char)hal_ver_code : ' ');
    log_i("FreeRTOS: %s", tskKERNEL_VERSION_NUMBER);
    log_i("Device ID: 0x%lX", HAL_GetDEVID());
    log_i("Revision ID: 0x%lX", HAL_GetREVID());
    log_i("Flash size: %dk", *flash_size);
    log_i("SysClock: %ldMHz", HAL_RCC_GetSysClockFreq() / 1000000);
    log_i("Unique ID: %08lX%08lX%08lX",
        __bswap32(HAL_GetUIDw0()),
        __bswap32(HAL_GetUIDw1()),
        __bswap32(HAL_GetUIDw2()));
    log_i("App version: %s", app_descriptor->version);
    log_i("Build date: %s", app_descriptor->build_date);
    log_i("Build describe: %s", app_descriptor->build_describe);
    log_i("Build checksum: %08lX", __bswap32(app_descriptor->crc32));

    if (startup_bkp0r & RCC_CSR_PINRSTF) {
        log_i("Pin reset");
    }
    if (startup_bkp0r & RCC_CSR_PORRSTF) {
        log_i("Power on reset");
    }
    if (startup_bkp0r & RCC_CSR_SFTRSTF) {
        log_i("Software reset");
    }
    if (startup_bkp0r & RCC_CSR_OBLRSTF) {
        log_i("Options bytes loading reset");
    }
    if (startup_bkp0r & RCC_CSR_IWDGRSTF) {
        log_i("IWDG reset");
    }
    if (startup_bkp0r & RCC_CSR_WWDGRSTF) {
        log_i("WWDG reset");
    }
    if (startup_bkp0r & RCC_CSR_LPWRRSTF) {
        log_i("Low-Power reset");
    }

    log_i("-----------------------");
}

int main(void)
{
    /*
     * Initialize the HAL, which will reset of all peripherals, initialize
     * the Flash interface and the Systick.
     */
    HAL_Init();

    /* Configure the system clock */
    system_clock_config();

    /* Read startup flags set by the bootloader */
    read_startup_flags();

    /* Initialize the watchdog */
    iwdg_init();

    /* Initialize the debug UART */
    usart1_uart_init();

    /* Initialize the rest of the configured peripherals */
    gpio_init();
    i2c1_init();
    tim2_init();
    spi1_init();
    crc_init();
    dma_init();
    adc_init();
    usb_init();

    watchdog_refresh();

    /* Initialize the RTC */
    rtc_init();

    /* Initialize the FreeRTOS scheduler */
    osKernelInitialize();

    /*
     * Note: Initialization code from this point forward may call FreeRTOS
     * functions that have a side-effect of disabling all interrupts, including
     * the one necessary for the HAL tick timer to function.
     * Starting the FreeRTOS scheduler at the end of this function should
     * make things return to normal behavior.
     */

    /* Initialize the logger */
    logger_init();

    /* Print the initial startup messages */
    startup_log_messages();

    watchdog_refresh();

    /* Create the main task */
    task_main_init();

    /* Start scheduler */
    log_i("Starting scheduler");
    osKernelStart();
}

void HAL_GPIO_EXTI_Callback(uint16_t GPIO_Pin)
{
    if (GPIO_Pin == SENSOR_INT_Pin) {
        sensor_int_handler();
    } else {
        keypad_int_handler(GPIO_Pin);
    }
}

void HAL_ADC_ConvCpltCallback(ADC_HandleTypeDef *hadc)
{
    UNUSED(hadc);
    adc_completion_callback();
}

/**
  * @brief  Period elapsed callback in non blocking mode
  * @note   This function is called  when TIM6 interrupt took place, inside
  * HAL_TIM_IRQHandler(). It makes a direct call to HAL_IncTick() to increment
  * a global variable "uwTick" used as application time base.
  * @param  htim : TIM handle
  * @retval None
  */
void HAL_TIM_PeriodElapsedCallback(TIM_HandleTypeDef *htim)
{
    if (htim->Instance == TIM6) {
        HAL_IncTick();
    }
}

void HAL_RTCEx_WakeUpTimerEventCallback(RTC_HandleTypeDef *hrtc)
{
    UNUSED(hrtc);
    state_suspend_rtc_wakeup_handler();
}

void error_handler(void)
{
    __disable_irq();
    __ASM volatile("BKPT #01");
    while (1) { }
}

#ifdef USE_FULL_ASSERT
/**
 * @brief  Reports the name of the source file and the source line number
 *         where the assert_param error has occurred.
 * @param  file: pointer to the source file name
 * @param  line: assert_param error line source number
 * @retval None
 */
void assert_failed(uint8_t *file, uint32_t line)
{
    printf("Assert failed: file %s on line %ld", file, line);
}
#endif /* USE_FULL_ASSERT */

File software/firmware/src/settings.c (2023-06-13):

#include "settings.h"

#define LOG_TAG "settings"

#include <printf.h>
#include <string.h>
#include <math.h>
#include <elog.h>

#include "util.h"

extern CRC_HandleTypeDef hcrc;

static HAL_StatusTypeDef settings_read_header(bool *valid);
static HAL_StatusTypeDef settings_write_header();

static bool settings_init_cal_sensor(bool force_clear);
static bool settings_clear_cal_sensor();
static bool settings_init_cal_target(bool force_clear);
static bool settings_clear_cal_target();
static bool settings_init_user_settings(bool force_clear);
static bool settings_clear_user_settings();


static void settings_set_cal_light_defaults(settings_cal_light_t *cal_light);
static bool settings_load_cal_light();
static void settings_set_cal_gain_defaults(settings_cal_gain_t *cal_gain);
static bool settings_load_cal_gain();
static void settings_set_cal_slope_defaults(settings_cal_slope_t *cal_slope);
static bool settings_load_cal_slope();
static void settings_set_cal_reflection_defaults(settings_cal_reflection_t *cal_reflection);
static bool settings_load_cal_reflection();
static void settings_set_cal_transmission_defaults(settings_cal_transmission_t *cal_transmission);
static bool settings_load_cal_transmission();
static void settings_set_user_usb_key_defaults(settings_user_usb_key_t *usb_key);
static bool settings_load_user_usb_key();
static void settings_set_user_idle_light_defaults(settings_user_idle_light_t *idle_light);
static bool settings_load_user_idle_light();
static void settings_set_user_display_format_defaults(settings_user_display_format_t *display_format);
static bool settings_load_user_display_format();

static HAL_StatusTypeDef settings_read_buffer(uint32_t address, uint8_t *data, size_t data_len);
static HAL_StatusTypeDef settings_write_buffer(uint32_t address, const uint8_t *data, size_t data_len);
static HAL_StatusTypeDef settings_erase_page(uint32_t address, size_t len);
#if 0
static float settings_read_float(uint32_t address);
static HAL_StatusTypeDef settings_write_float(uint32_t address, float val);
#endif
static uint32_t settings_read_uint32(uint32_t address);
static HAL_StatusTypeDef settings_write_uint32(uint32_t address, uint32_t val);

/*
 * Header Page (128b)
 * Mostly unused at the moment, will be populated if any top-level system
 * data needs to be stored. Unlike other pages, it begins with a magic
 * string.
 */
#define PAGE_HEADER        (DATA_EEPROM_BASE + 0x0000UL)
#define PAGE_HEADER_SIZE   (128)
#define HEADER_MAGIC       (PAGE_HEADER + 0U) /* "DENSITOMETER\0" */
#define HEADER_START       (PAGE_HEADER + 16U)
#define HEADER_VERSION     1UL

/*
 * Sensor Calibration Data (128b)
 * This page contains data specific to calibration of the sensor behavior
 * without taking any reference targets into account. It is likely that
 * the data stored here will be considered part of factory calibration,
 * unlikely to be performed by a user.
 */
#define PAGE_CAL_SENSOR             (DATA_EEPROM_BASE + 0x0080UL)
#define PAGE_CAL_SENSOR_SIZE        (128)
#define PAGE_CAL_SENSOR_VERSION     1UL

#define CONFIG_CAL_GAIN             (PAGE_CAL_SENSOR + 4U)
#define CONFIG_CAL_GAIN_SIZE        (28U)

#define CONFIG_CAL_SLOPE            (PAGE_CAL_SENSOR + 32U)
#define CONFIG_CAL_SLOPE_SIZE       (16U)

#define CONFIG_CAL_LIGHT            (PAGE_CAL_SENSOR + 48U)
#define CONFIG_CAL_LIGHT_SIZE       (12U)

/*
 * Target Calibration Data (128b)
 * This page contains data specific to calibration against reference targets
 * used to ensure the device is providing the correct readings. It is
 * something end users are expected to update periodically, based on
 * materials that may be included with the device.
 */
#define PAGE_CAL_TARGET                    (DATA_EEPROM_BASE + 0x0100UL)
#define PAGE_CAL_TARGET_SIZE               (128U)
#define PAGE_CAL_TARGET_VERSION            1UL

#define CONFIG_CAL_REFLECTION              (PAGE_CAL_TARGET + 4U)
#define CONFIG_CAL_REFLECTION_SIZE         (20U)

#define CONFIG_CAL_TRANSMISSION            (PAGE_CAL_TARGET + 24U)
#define CONFIG_CAL_TRANSMISSION_SIZE       (16U)

/*
 * User Settings (128b)
 * This page contains any user settings that the device may need to store.
 */
#define PAGE_USER_SETTINGS         (DATA_EEPROM_BASE + 0x0180UL)
#define PAGE_USER_SETTINGS_SIZE    (128)
#define PAGE_USER_SETTINGS_VERSION 3UL

#define CONFIG_USER_USB_KEY        (PAGE_USER_SETTINGS + 4U)
#define CONFIG_USER_USB_KEY_SIZE   (12U)

#define CONFIG_USER_IDLE_LIGHT      (PAGE_USER_SETTINGS + 16U)
#define CONFIG_USER_IDLE_LIGHT_SIZE (12U)

#define CONFIG_USER_DISPLAY_FORMAT      (PAGE_USER_SETTINGS + 28U)
#define CONFIG_USER_DISPLAY_FORMAT_SIZE (8U)
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

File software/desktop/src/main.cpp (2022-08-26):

#include <iostream>

#include <QApplication>
#include <QLocale>
#include <QTranslator>
#include <QCommandLineParser>
#include <QSerialPortInfo>
#include <QTimer>
#include <QDebug>

#ifdef Q_OS_MACX
#include "MacUtil.h"
#endif

#include "mainwindow.h"
#include "headlesstask.h"

namespace
{
HeadlessTask::Command headlessCommand = HeadlessTask::CommandUnknown;
QString headlessArg;
QString connectPort;
}

bool handleCommandLine(const QCoreApplication &app)
{
    // Setup the command line parser
    QCommandLineParser parser;
    parser.addHelpOption();
    parser.addVersionOption();

    // Add specific command line options
    QCommandLineOption listOption(QStringList() << "l" << "list",
                                  QCoreApplication::translate("main", "List attached devices."));
    parser.addOption(listOption);

    QCommandLineOption portOption(QStringList() << "p" << "port",
                                  QCoreApplication::translate("main", "Connect to device at the selected port."),
                                  QCoreApplication::translate("main", "port"));
    parser.addOption(portOption);

    QCommandLineOption infoOption(QStringList() << "i" << "info",
                                  QCoreApplication::translate("main", "Query device system info."));
    parser.addOption(infoOption);

    QCommandLineOption exportOption(QStringList() << "export",
                                    QCoreApplication::translate("main", "Export device settings to file."),
                                    QCoreApplication::translate("main", "file"));
    parser.addOption(exportOption);

    // Parse the command line
    parser.process(app);

    if (parser.isSet(listOption)) {
        bool hasDevices = false;
        const auto infos = QSerialPortInfo::availablePorts();
        for (const QSerialPortInfo &info : infos) {
            // Filter the list to only contain devices that match the VID/PID
            // actually assigned to the Printalyzer Densitometer
            if (!(info.vendorIdentifier() == 0x16D0 && info.productIdentifier() == 0x10EB)) {
                continue;
            }
            std::cout << info.portName().toStdString()
                      << " " << info.description().toStdString()
                      << " [" << info.serialNumber().toStdString() << "]"
                      << std::endl;
            hasDevices = true;
        }
        if (!hasDevices) {
            std::cout << "No attached devices." << std::endl;
        }

        return true;
    }

    QString portValue = parser.value(portOption);
    if (!portValue.isEmpty()) {
        std::cout << "Connecting to " << portValue.toStdString() << std::endl;
        connectPort = portValue;
    }

    if (parser.isSet(infoOption) && headlessCommand == HeadlessTask::CommandUnknown) {
        headlessCommand = HeadlessTask::CommandSystemInfo;
    }

    if (parser.isSet(exportOption) && headlessCommand == HeadlessTask::CommandUnknown) {
        headlessCommand = HeadlessTask::CommandExportSettings;
        headlessArg = parser.value(exportOption);
    }

    return false;
}

int main(int argc, char *argv[])
{
    QApplication a(argc, argv);
    QApplication::setApplicationName("Printalyzer Densitometer Desktop");
    QApplication::setApplicationVersion("0.2");
    QApplication::setOrganizationName("Dektronics, Inc.");
    QApplication::setOrganizationDomain("dektronics.com");
    QApplication::setWindowIcon(QIcon(":/icons/appicon.png"));

    QTranslator translator;
    const QStringList uiLanguages = QLocale::system().uiLanguages();
    for (const QString &locale : uiLanguages) {
        const QString baseName = "densitometer_" + QLocale(locale).name();
        if (translator.load(":/i18n/" + baseName)) {
            a.installTranslator(&translator);
            break;
        }
    }

#ifdef Q_OS_MACX
    /* Force light theme for UI consistency */
    if (macIsInDarkTheme()) {
        macSetToLightTheme();
    }
#endif

    if (handleCommandLine(a)) {
        return 0;
    }

    if (headlessCommand != HeadlessTask::CommandUnknown) {
        HeadlessTask *task = new HeadlessTask(&a);
        task->setPort(connectPort);
        task->setCommand(headlessCommand, headlessArg);
        QTimer::singleShot(0, task, &HeadlessTask::run);
        QObject::connect(task, &HeadlessTask::finished, &a, &QCoreApplication::quit);
        return a.exec();
    } else {
        MainWindow w;
        w.show();

        if (!connectPort.isEmpty()) {
            w.connectToPort(connectPort);
        }
        return a.exec();
    }
}

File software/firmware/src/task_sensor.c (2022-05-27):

#include "task_sensor.h"

#define LOG_TAG "task_sensor"
#include <elog.h>

#include <math.h>
#include <cmsis_os.h>
#include <FreeRTOS.h>
#include <queue.h>

#include "stm32l0xx_hal.h"
#include "settings.h"
#include "tsl2591.h"
#include "sensor.h"
#include "light.h"
#include "util.h"
#include "cdc_handler.h"

/**
 * Sensor control event types.
 */
typedef enum {
    SENSOR_CONTROL_STOP = 0,
    SENSOR_CONTROL_START,
    SENSOR_CONTROL_SET_CONFIG,
    SENSOR_CONTROL_SET_LIGHT_MODE,
    SENSOR_CONTROL_INTERRUPT
} sensor_control_event_type_t;

typedef struct {
    tsl2591_gain_t gain;
    tsl2591_time_t time;
} sensor_control_config_params_t;

typedef struct {
    sensor_light_t light;
    bool next_cycle;
    uint8_t value;
} sensor_control_light_mode_params_t;

typedef struct {
    uint32_t sensor_ticks;
    uint32_t light_ticks;
    uint32_t reading_count;
} sensor_control_interrupt_params_t;

/**
 * Sensor control event data.
 */
typedef struct {
    sensor_control_event_type_t event_type;
    osStatus_t *result;
    union {
        sensor_control_config_params_t config;
        sensor_control_light_mode_params_t light_mode;
        sensor_control_interrupt_params_t interrupt;
    };
} sensor_control_event_t;

/* Global I2C handle for the sensor */
extern I2C_HandleTypeDef hi2c1;

static volatile bool sensor_initialized = false;
static volatile uint32_t pending_int_light_change = 0;
static volatile uint32_t light_change_ticks = 0;
static volatile uint32_t reading_count = 0;

/* Sensor task state variables */
static bool sensor_running = false;
static tsl2591_gain_t sensor_gain = TSL2591_GAIN_LOW;
static tsl2591_time_t sensor_time = TSL2591_TIME_100MS;
static bool sensor_discard_next_reading = false;

/* Queue for low level sensor control events */
static osMessageQueueId_t sensor_control_queue = NULL;
static const osMessageQueueAttr_t sensor_control_queue_attrs = {
    .name = "sensor_control_queue"
};

/* Queue to hold the latest sensor reading */
static osMessageQueueId_t sensor_reading_queue = NULL;
static const osMessageQueueAttr_t sensor_reading_queue_attrs = {
    .name = "sensor_reading_queue"
};

/* Semaphore to synchronize sensor control calls */
static osSemaphoreId_t sensor_control_semaphore = NULL;
static const osSemaphoreAttr_t sensor_control_semaphore_attrs = {
    .name = "sensor_control_semaphore"
};

/* Sensor control implementation functions */
static osStatus_t sensor_control_start();
static osStatus_t sensor_control_stop();
static osStatus_t sensor_control_set_config(const sensor_control_config_params_t *params);
static osStatus_t sensor_control_set_light_mode(const sensor_control_light_mode_params_t *params);
static osStatus_t sensor_control_interrupt(const sensor_control_interrupt_params_t *params);
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

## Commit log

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2021-06-10 Switched debug connector to a Tag-Connect TC2070
    This makes it easier to put on the opposite side of the board, where it
    won't be obstructed.
    [main-board.kicad_pcb, main-board.sch]
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2021-06-10 Fixed size of transmission LED board
    Mistakenly used diameter as the radius of the reference circles.
    [trans-led-board.kicad_pcb]
2021-06-13 Moved display connector to near board edge
    Also moved the display position silkscreen a bit, but the final location
    is TBD pending construction of the Rev A prototype. As such, the current
    3D model of the display doesn't really line up so well anymore.
    The idea is that because the display needs to be raised a bit above the
    PCB for improved visibility, this position change will allow for that
    flexibility. Since its hard to accurately measure and remodel the
    display location at this stage, and because the enclosure top is the
    easiest component to tweak/recreate, its position will be measured from
    the first build and fed back into the silkscreen later.
    [main-board.kicad_pcb]
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2021-06-13 Test point cleanup
    We don't have clearance for test point attachments on top of the PCB.
    Instead, the rear screw holes will be connected to ground, and 5V for
    testing will just be supplied via the USB connector like normal power.
    [main-board.kicad_pcb, main-board.sch]
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2021-07-09 Initial implementation of transmission density
    Calibration for transmission is based on the "basic count" sensor values
    for no film and a CAL-HI target, as well as the known density of that
    CAL-HI target.
    It may make sense to switch to storing reflection density as a "basic
    count" value (rather than a log10 of such) too, simply to allow for more
    flexibility in calculation. However, that will be left to later.
    There's still room for improvement in the sensor read loop, as it
    sometimes has glitches with the startup process on high density targets.
    [cdc_handler.c, settings.c]
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2021-07-13 Implemented state controller based UI and menu system
    Built out a state controller to manage device interaction states,
    covering all the basic measurement and display modes.
    Created a basic home screen mechanism for taking reflection and
    transmission density measurements.
    Built out a menu system within its own state, using a sub-state to track
    where in the menu the user is. This avoids keeping the menus too far
    removed from the main state loop, even if they're still somewhat
    separate.
    Created a new "densitometer" module to encapsulate all the code for
    doing reflection/transmission measurements and calibration.
    Sensor gain calibration is still in the "sensor" module, but might
    get partiall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
    [cdc_handler.c, display.c, main.c]
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2021-07-27 Add initial support for detect switch
    Since the updated enclosure now allows the detect switch (BTN5) to work
    correctly, we need some initial software support for it. As this switch
    does not currently act like as an event trigger, like the other buttons,
    it will be handled differently for now.
    - Disabled interrupt support for BTN5
    - Added functions to wrap polling the BTN5 state
    - Added a BTN5 indicator on the diagnostic screen
    - Updated the display states so that BTN5 toggles the idle-state read
    lights on and off, and gates whether or not measurements can be taken
    If the detect switch isn't contacting correctly, then the device will
    behave as though its always in the "pushing down" posi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
    [keypad.c, main.c]
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2021-08-16 Fixed STL files for cover pieces
    Both of these somehow ended up being the main cover, albeit different
    versions. This should fix it.
    [dens-base-cover.stl, dens-main-cover.stl]
2021-08-30 Removed date and revision markings in prep for updates
    This is to prevent old values from being left in the next revision. New
    values will be added when Rev B is finished.
    [main-board.kicad_pcb, main-board.sch]
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2021-08-30 Changed MCU on main board and routed pin changes
    Swapped the MCU from the L052K to the K072K, pulling in all pin
    assignment changes from the CubeMX data.
    Added extra bypass capacitor and sensor interrupt (/w pull-up) to
    schematic.
    Updated PCB routing to reflect changes, which included rearranging the
    layout of many bypass capacitors and making a variety of adjustments to
    routing in the MCU area.
    Left a placeholder for a BOOT0 selector button that will be added in the
    future.
    Note: Decided to stick with KiCad's stock QFN-32 footprint instead of
    using the custom one (based on the ST datasheet) used in the previous
    revision. This is because the pads on the KiCad footprint extend further
    out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
    [main-board.kicad_pcb, main-board.sch]
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2021-08-31 Moved boot select switch to avoid clearance issues
    This moves it under the Tag-Connect footprint, which is probably an okay
    place to put it. Just a bit concerned about how much that footprint
    causes routing issues and plane breakup.
    Refs #11
    [main-board.kicad_pcb]
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2021-09-17 Fixed missing silkscreen date and revision code
    Unfortunately this didn't make the prototype fab run, but it will be
    there for any future builds.
    [main-board.kicad_pcb]
2021-09-17 Fixed ferrite bead component description
    Two identical parts should have identical descriptions to make the BOM
    data nicer.
    [main-board.kicad_pcb, main-board.sch]
2021-09-22 Migrate project from Rev A hardware to Rev B hardware support
    This is a basic first pass, which doesn't involve any functional
    changes of note.
    Imported the CubeMX code generation dump, which includes changes for:
    - Switching from the L052 to the L072 MCU
    - Necessary GPIO pin assignment changes as part of the switch
    - Adding FreeRTOS to the build, and making any necessary adjustments
    (e.g. moving HAL off systick)
    Disabled -flto again for now, as we've gained a lot of headroom.
    While FreeRTOS is now included in the build, it is not used yet in any
    functional way. Migration of runtime behavior over to FreeRTOS tasks
    will happen in future commits.
    [board_config.h, main.c]
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2021-10-03 Major sensor task refactoring and LED cal integration
    Split the sensor module into separate files, where one contains the
    sensor task code and the other contains data types and utility functions
    for interacting with it.
    Moved responsibility for LED control into the sensor task, giving the
    sensor task the ability to very tightly control the timing of LED
    activation in relation to the sensor's integration cycle.
    Added a calibration routine that runs the LED through a full 2-minute on
    cycle, measures its brightness over time, then does logarithmic
    regression to find a curve that models the change in brightness. This
    will be used in a future commit to make the general sensor read loop
    capable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
    [cdc_handler.c, main.c, settings.c]
2021-10-03 Updated regular measurements to use light calibration data
    Also fixed some issues with tracking light on time in the sensor task.
    [task_sensor.c]
2021-10-05 Fixed constness of some read-only data and increased FreeRTOS heap
    Several variables that contained read-only data (e.g. display assets)
    were not set as const and thus ended up residing in RAM. Fixing this
    increased the amount of available RAM for the FreeRTOS heap, where more
    was needed.
    [task_main.c]
2021-10-05 Added more tusb callback handling and write mutex
    Added the tusb cdc callback for RX, which releases a semaphore that the
    main cdc task loop now blocks on. This removes the need to put a small
    idle delay in that loop, so it can behave more correctly.
    Added a write mutex to make it possible for code outside of the cdc
    handler to send data out without conflicting.
    Still need to work on handling the case of a disconnected terminal.
    [cdc_handler.c]
2021-10-06 Major cleanup of CDC transmit handling
    - DTR and baud rate are now used to detect when a valid connection is
    available.
    - A semaphore is used to synchronize transmit, and determine when the
    transmit has failed due to a host not obeying the assumptions made for
    DTR behavior.
    - Failed transmits (due to timeout) are now handled by resetting the
    endpoint (stall/clear-stall) and putting it into a disconnected state
    until the next line state DTR change.
    It should now be safe to write code that transmits whenever we feel
    like, without having to worry about whether or not a host is listening.
    [cdc_handler.c]
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2021-10-06 Replaced newlib printf with mpaland printf across the code
    This is mostly a stdio.h to printf.h search and replace, in the main
    firmware code and some bits of easylogger.
    There still may be more cruft to hunt down later on.
    Making this change should give us more control over string formatting,
    and make it possible to use more robust formatting of floating point
    values.
    [cdc_handler.c, display.c, main.c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]
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2021-10-07 Disable and/or remove LED calibration code paths
    The first attempt at LED profiling may work well over a 30+ second
    cycle, but is quite inaccurate and potentially causes problems within
    the shorter period in which we do actual measurements. For now its safer
    to completely rip it out until it can be reevaluated.
    The underlying calibration routines are being left in, reachable only
    via the CDC interface, as a way of comparing different LED
    configurations of the hardware. Even those may be removed eventually.
    Ultimately, the chosen solution is going to need to fall into one of two
    categories:
    1. A much fancer rethinking of how to profile LED behavior, possibly
    involving polynomial interpol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
    [cdc_handler.c]
2021-10-07 Cleaned up sensor task control events and added iteration tracking
    Now using a more strongly typed way of passing parameters between the
    sensor task and various event sources.
    Added tracking of sensor integration cycle tracking to the sensor
    readings, so we can actually keep track of how many cycles have happened
    since turning the sensor on. This prevents cycles with discarded data
    from messing up any code that cares about cycle count.
    [task_sensor.c]
2021-10-11 Updated display task to avoid unnecessary light change calls
    This is a lot easier than implementing a fancy pending-change-tracking
    mechanism for sensor task events. Its also the only sensor task command
    where we're not always being deliberate about timing around invoking it,
    so its not worth putting in the extra complexity.
    [task_sensor.c]
2021-10-11 Added error handling paths to sensor task commands
    All sensor tasks now have a response code. Since external commands are
    typically handled synchronously, the response code is populated as part
    of the process of handling that command.
    Also added code to check this response code, so that failures inside the
    sensor task now propagate upward.
    Fixes #13
    [task_sensor.c]
2021-10-11 Initial app descriptor and checksum implementation
    Added an app descriptor block to the application and its build process,
    along with a checksum that is validated on firmware startup.
    Deciding whether to actually do the validation, or how to react to a
    validation failure, is still somewhat TBD. By the point in the startup
    process where the validation code is running, a fair bit of the system
    initialization has already been attempted. However, not enough
    initialization has been performed to actually display any error message
    to a user.
    It might make sense to simply remove any error halting in favor of just
    setting a flag that's made visible elsewhere if anyone cares. However,
    for now, this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
    [main.c]
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2021-10-16 The great USB-CDC command protocol rewrite
    Added data structures and utility functions for handling commands and
    command responses in a new standardized format.
    Reimplemented the majority of the old commands within the structure of
    the new format, omitting a few that no longer made sense to retain.
    Implemented a special "remote control" state for the UI state controller
    - Several CDC commands will conflict with the local UI. To make them work,
    we need a way to put the device into a special state that locks out
    normal user interaction.
    - This remote control state doesn't currently do anything useful on its
    own. There is an expectation that the CDC handler will do any real work
    durin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
    [cdc_handler.c, display.c, main.c]
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2021-10-21 Added slope correction to density readings
    This includes a step that uses the slope correction values,
    and also changes the extended CDC data format to include both corrected
    and uncorrected raw readings.
    Refs #12
    [cdc_handler.c]
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2021-10-25 Disable light source characterization code
    These routines are only used to evaulate LED behavior across hardware
    changes, and are no longer being seriously considered as part of normal
    device operation. Keeping them in the code base so they can be enabled
    if needed, but disabling them from normal firmware builds.
    Once the hardware is finalized, they may be removed altogether.
    [cdc_handler.c]
2021-10-25 Remove support for non-HEX-encoded floating point commands
    With the exception of the basic density reading output format, the
    USB-CDC interface is intended for use with a dedicated desktop
    application or utility. There is no longer any need to keep this
    interface usable by a human who does not have access to such a utility.
    The encoded hex format is much easier to handle consistently than
    human-readable floating point formats, and requires less library code
    too. As such, for the sake of firmware simplicity, this will be the
    only format supported for most of the commands in the USB-CDC protocol.
    [cdc_handler.c]
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2021-10-26 Move target zero'ing to the display state
    Now that we have better key event handling, move the setting and
    clearing of a "target relative zero" measurement from the measurement
    state to the display state. It is also now triggered by a long-press of
    the up/down buttons, rather than an awkward button combination.
    Fixes #5
    [keypad.c]
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2021-11-05 Minor fixes to bootloader flash routines
    Disable interrupts during half-page write, since its possible that ISRs
    were messing things up if the timing was just right. Resolving this
    without disabling ISRs would be way too complicated.
    Fixed HAL feature macro handling in the board_api.h file.
    [board.c]
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2021-11-15 Update LED footprints for thermal properties
    Fixes naming convention of thermally-enhanced LED footprints to be
    closer to the KiCad convention, and separates into two versions. One
    with thermal vias and one without.
    Updated transmission board metadata to referene the correct new
    footprint name.
    Updated main board to use the new version of the new footprint without
    thermal vias.
    Fixes #22
    [main-board.kicad_pcb, main-board.sch, trans-led-board.kicad_pcb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]
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2021-11-16 Added USB-C connector to main board schematic
    - Switched the USB Micro-B connector to a USB 2.0 capable USB-C connector
    - Implemented connections based on AN5225 guidance, which just involves
    connecting the D+/D- pins together and adding CC1/CC2 pull-down
    resistors. This is the simplest way to implement it.
    - Increased sheet size from US Letter to US Legal to avoid the the need
    to break the schematic into multiple pages for just this one change,
    as the USB-C connector symbol is much bigger
    - Linked the connector to the TVS diode and power filtering components
    via labels, to avoid the schematic getting too messy in that area.
    Refs #18
    [main-board.sch]
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2021-11-30 Update schematic properties
    Changed all revision labeling to "C" with today's date. This is subject
    to change when the boards are sent for manufacturing, but removing
    placeholders make mistakes here less likely in the future.
    Set grid and drill origins to what they're hopefully supposed to be. Not
    sure how much this matters, but it probably won't hurt.
    More layout nitpicking and review changes may happen between now and
    pre-production, but the general design and layout for Rev C can
    probably be considered sufficiently done for now.
    [main-board.kicad_pcb, main-board.sch, trans-led-board.kicad_pcb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]
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2021-12-09 Added initial use of the IWDG watchdog to the system
    At this stage, we are mainly adding this to prevent any system freezes
    caused by spurious events or faults. It is unlikely that more complex
    software problems, such as deadlocks, will be caught by the current
    implementation.
    The bootloader now initializes the watchdog with a 2 second timeout,
    and kicks it in a few critical places. Once the main firmware is
    started, it reduces that to a more sensible 0.5s period and kicks it
    inside the FreeRTOS idle hook.
    As such, this will only catch cases where the system goes directly into
    an infinite loop due to a fault, or a task prevents the FreeRTOS
    scheduler from running. In rare cases where a lon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
    [board.c, display.c, main.c]
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2022-01-03 Migrate project from KiCad v5 to v6
    - Update symbol library files for KiCad 6
    - Moved location of symbol datasheet elements, since v6 suddenly decided
    they should always be visible in the symbol editor
    - Update transmission LED board for KiCad 6
    - No real changes needed here, just the automated conversion and cleanup
    - Also adjusted silkscreen rev/date fields to use variables
    - Update main board for KiCad 6
    - Fixed symbol and 3D model associations where necessary
    - Ran automated housekeeping fixups
    - Adjusted silkscreen rev/date fields to use variables
    - Made changes to main board PCB to make DRC happy
    - Made minor tweaks to DRC rules based on fab specs
    - Tweaked footprint co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
    [main-board.kicad_pcb, main-board.kicad_sch, main-board.sch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]
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2022-01-06 Add bulk capacitor to VBUS input
    Added a 4.7uF capacitor just past the VBUS input ferrite bead, before
    the +5V line goes to the 5V power plane.
    Decided to stick with 4.7uF instead of 10uF for component commonality
    and to avoid going past 10uF when including the LDO input capacitor.
    Changed the 4.7uF capacitor used in both areas of the design to one with
    a 25V rating, just to be safe.
    Updated PCB layout and nudged some silkscreen bits around.
    Fix #26
    [main-board.kicad_pcb, main-board.kicad_sch]
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2022-01-06 Changed LED_EN pins and added pull-down resistors
    Switched TLED_EN and RLED_EN pins, per the preceding CubeMX spec update
    Added pull-down resistors to TLED_EN, RLED_EN, and DISP_RES to ensure
    clean transitions and reliable non-floating behavior during startup and
    cases when the firmware hasn't configured these pins yet.
    Fix #25
    [main-board.kicad_pcb, main-board.kicad_sch]
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2022-01-18 Various panel related adjustments
    Changed tab settings and positions for better size and component
    clearance.
    Nudged some traces around.
    [main-board.kicad_pcb, main-board.kicad_sch]
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2022-02-03 Update firmware and bootloader for Rev C hardware changes
    Renamed relevant linker/startup files based on the new MCU variant.
    Changed flash address/size constants for 192k total, with 160k for the
    firmware and 32k for the bootloader. This extra headroom will make it
    easier to clean up some things, and to make the bootloader more flexible
    and reliable in the future.
    Changed pin configurations based on the LED control pin reassignments on
    the Rev C board.
    Fix bootloader code that checks for erased flash pages.
    While most MCUs set erased flash to 0xFF, the STM32L0 sets its erased
    flash to 0x00. Need to adjust the check, to prevent "not zero" write
    failures.
    Fix #30
    [board.c, board_config.h, main.c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]
2022-02-04 Fix UID-handling code across all uses
    The 96-bit UID from the MCU is read in a variety of places, for logging
    purposes, system info purposes, and for USB device serial purposes. This
    code was broken, in that it was not correctly reading the last word of
    the UID.
    This change fixes that, and uses the HAL wrapper functions to make it
    more obvious how its working.
    The ideal way to stringify the UID, in terms of format and endianness,
    is unclear. So right now its more important that all the different
    implementations produce the same output.
    Fix #32
    [board.c, cdc_handler.c, main.c]
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2022-02-16 Redesigned the settings storage format
    The new settings storage format is designed to improve the ability to
    adapt to future changes, and to reduce the likelihood of partial writes
    causing malformed data.
    The first step was to split settings out into a series of distinct
    "pages" of persisted data:
    - Header page
    - Sensor calibration page
    - Target calibration page
    - User settings page
    For now, the header page is little more than a placeholder to detect a
    fresh device, but it could be used to contain manufacturing data if the
    need arises.
    Likewise, the user settings page is currently empty. It will gain
    contents when/if user settings or persisted state is added to the
    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
    [main.c, settings.c]
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2022-02-21 Added USB-CDC command for wiping configuration data
    This command is designed to be hard to send by accident, as the device
    needs to be in remote control mode and the command arguments are also
    device/firmware specific. It also resets the device after running.
    Additionally, code was added to the settings EEPROM helper routines to
    clear flash controller error flags prior to running. This removes the
    need to explicitly workaround an unintentionally set WRP error flag in
    the HAL code itself.
    [cdc_handler.c, settings.c]
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2022-02-28 Implement ADC oversampling to improve reading stability
    This change enables 16x oversampling on the ADC peripheral, and converts
    all the post-conversion calculations to operate in floating point (even
    though the results are still integers). This change greatly improves the
    stability of Vdda and Temperature readings, which will be neede for
    device characterization.
    If there is a need to later incorporate these into the sensor read loop,
    then the internal representation of the temperature result will likely need
    to be changed to floating point as well.
    After these changes, the measurement routine takes approximately 5ms to
    execute. If that ever needs to be a background operation with resepec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
    [adc_handler.c, main.c]
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2022-03-21 Refactor transmission/reflection components with overlapping logic
    The measure and display states are almost identical for transmission and
    reflection, with only minor adjustments to call into different functions
    and display different elements.
    The front-end densitometer API likewise has the same issue, leading to
    the above.
    This change refactors the densitometer API to hide mode-specific
    elements behind an opaque struct and instead use the same set of
    public function calls for both mode cases.
    It then refactors the measure and display states to share the same
    implementation functions for both modes, adding necessary
    parameterization differences.
    [cdc_handler.c]
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
